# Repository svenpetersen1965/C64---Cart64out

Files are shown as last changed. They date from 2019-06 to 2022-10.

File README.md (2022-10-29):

# C64---Cart64out
Cart64out is a breakout board for the Commodore C64 Expansion Port 

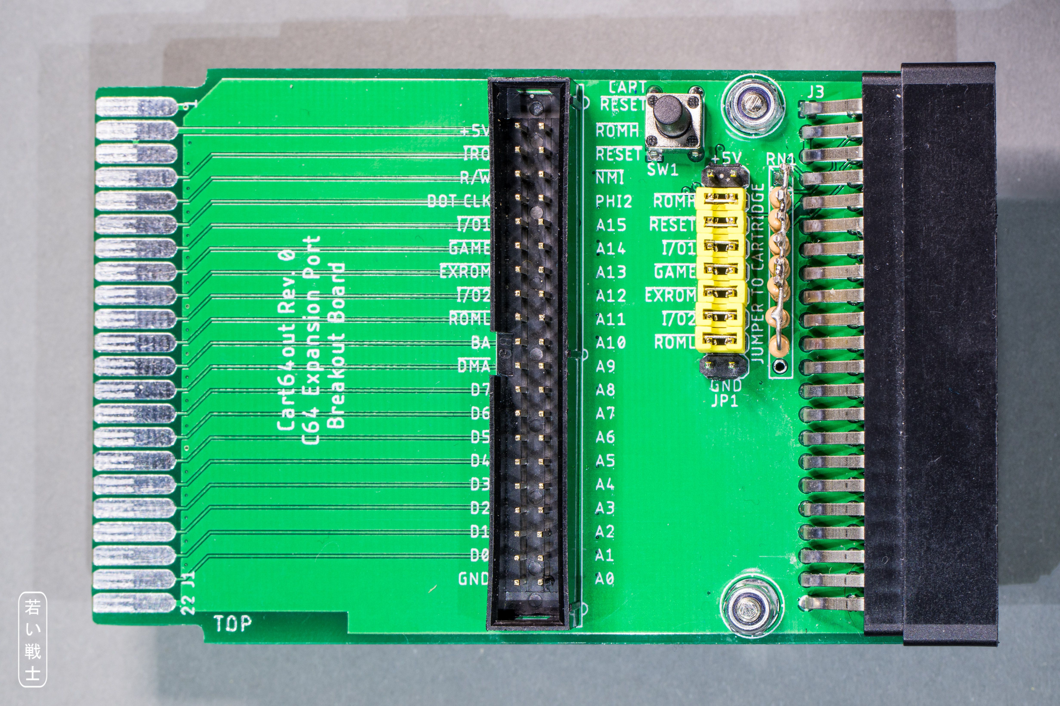
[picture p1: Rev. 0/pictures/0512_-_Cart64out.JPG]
Cart64out


All signals of the C64 expansion port are connected to a box pin header. This way, they can be displayed 
with a logic analyzer or an oscilloscope. A helpful feature for analysing the functionality for a cartridge.
Some configuration and chip select signals are connected to a jumper, hence they can be interrupted by pulling 
a jumper, which might be useful for copying a cartridge. To provide a perfect timing for this, a micro controller 
could be connected to the Jumper JP1.

Also the signals from J2 can be connected to a bread board. The two GND and two +5V pins on JP1 are intended for this purpose.

# Rev. 0a
This revision is a derivative of Rev. 0. It offers two additional mounting holes, in case this board is used to be an extension of the port (not tested, yet).

# Rev. 1
Rev. one has four mounting holes and additional signals (/IRQ , /NMI and /DMA) on the pin header JP1. 
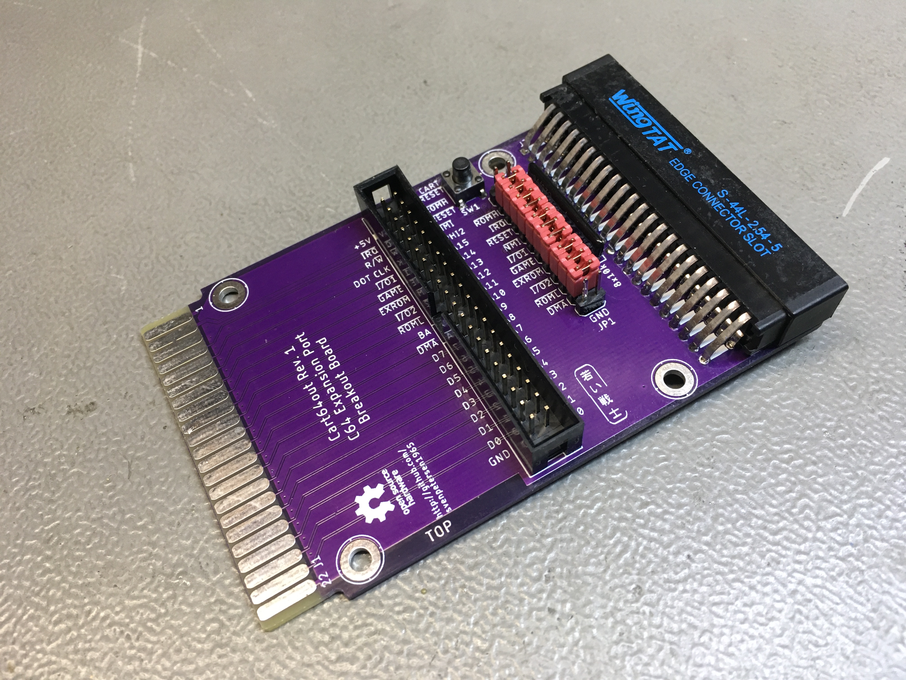
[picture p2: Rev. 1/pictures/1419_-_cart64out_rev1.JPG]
Cart64out


# Calculation of the BOM
The compnent prices (PBC included) were summed up. The total costs are 2.99€ (depending on the part sourcing). No shipping fees are included.

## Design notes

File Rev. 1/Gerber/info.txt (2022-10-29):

      
       Board: Cart64out
       Rev.:  1
  
       Files:
       ======
  
       All Gerber files are generated in extended gerber format (RS274X)
       *.TOP        : Film top copper
       *.BOT        :  -"- bottom copper
       *.STC        :  -"- top soldermask 
       *.STS        :  -"- bottom soldermask
       *.PLC        :  -"- silk screen top
       *.DK         : Drills plated Through (Excellon)
       *.NDK        : Drills not plated Through (Excellon)
       *.OUT        : Board outline

       Board Size:
       ===========
       Length     :   97.0 mm
       Width      :   62.0 mm
       Thickness  :   1.6 mm
       Material   :   FR 4
       Copper     :   35 um
       Surface    :   HASL
       
       Remarks:
       ========

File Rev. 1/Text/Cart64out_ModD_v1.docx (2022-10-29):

C64 Cart64out Rev. 1

Module description

# Introduction

This board is a breakout board for the C64 (C128) expansion port. It can also serve several other purposes:

- Expansion port breakout board for connecting a scope or logic analyzer
- Breakout board for connecting a bread board
- Cartridge read out and analysis tool
- A simple reset-switch

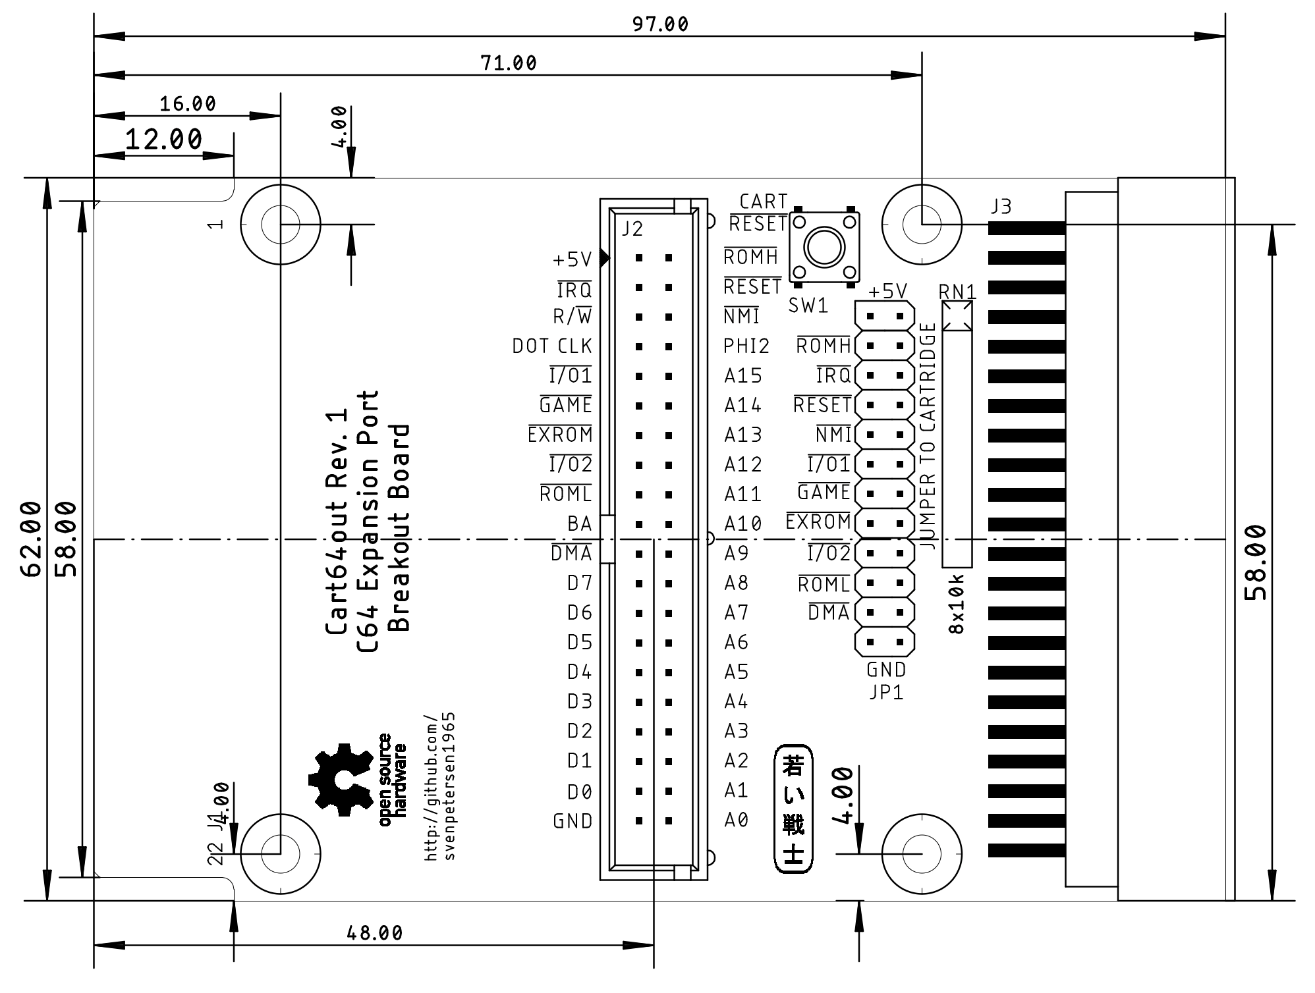
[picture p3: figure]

Figure 1: Cart64out dimensions

All signals of the expansion port are connected to the pin header J2. GND and +5V are only connected once to be able to use a standard 2x20p. pin header. All signals are connected to the edge connector J3. Some of those signals have to pass the jumper JP1, though, so they can be interrupted by pulling out the associated jumper. The resistor network RN1 serves as pull-up resistor on the cartridge side, so an open jumper means, that this signal is HIGH on the cartridge side.

The reset-switch SW1 is connected to the cartridge side of the reset signal. As long as the jumper labeled is closed, it is effective for the cartridge and the C64. While this jumper is open, it only resets the cartridge.

JP1 can also be controlled by a micro controller for a comfortable read out of the cartridge. The supply voltage +5V and GND are connected on adjacent pins for this purpose. Those jumper pins are not required to be closed with a jumper.

Signal | Pin | Pin | Signal
+5V | 1 | 2 | +5V
| 3 | 4
| 5 | 6
| 7 | 8
| 9 | 10
| 11 | 12
| 13 | 14
| 15 | 16
| 17 | 18
| 19 | 20
| 21 | 22
GND | 23 | 24 | GND

Table 1: Pinout of Jumper JP1

Cart64out aims at the experienced hardware amateur, who wants to get deeper into the functionality of C64 cartridges. It can also be helpful while repairing a C64, because some of the signals, like , PHI2 or DOT CLOCK or stuck address or data lines can be monitored by scope without opening the C64.

The drills serve to install bolts adjusted to height to support the Cart64out. A length of 17mm – 18mm works best for both sorts of cases (C64 and C64C).

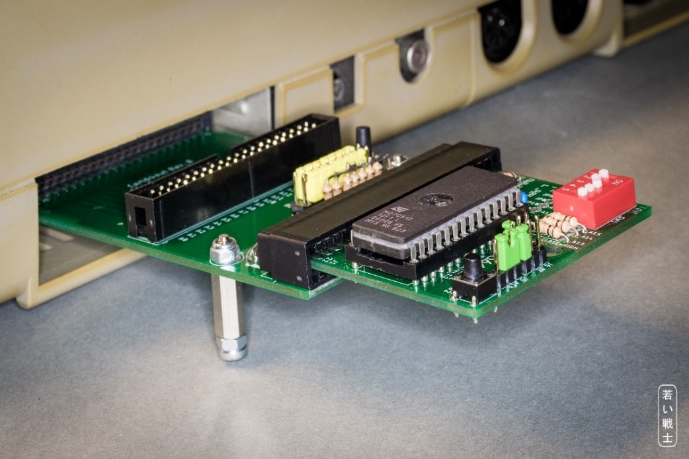
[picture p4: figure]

Figure 2: Supporting bolts

# Pinouts

## J1 – Expansion Port

Pin (TOP) | Signal | Pin | Signal (BOT)
1 | GND | A | GND
2 | +5V | B
3 | +5V | C
4 | | D
5 | R / | E | PHI2
6 | DOT CLOCK | F | A15
7 | | H | A14
8 | | J | A13
9 | | K | A12
10 | | L | A11
11 | | M | A10
12 | BA | N | A9
13 | | P | A8
14 | D7 | R | A7
15 | D6 | S | A6
16 | D5 | T | A5
17 | D4 | U | A4
18 | D3 | V | A3
19 | D2 | W | A2
20 | D1 | X | A1
21 | D0 | Y | A0
22 | GND | Z | GND

## J2 – Break out connector

2x20 box header, 2.54mm pitch

Pin | Signal | Pin | Signal
1 | +5V | 2
3 | | 4
5 | R / | 6
7 | DOT CLOCK | 8 | PHI2
9 | | 10 | A15
11 | | 12 | A14
13 | | 14 | A13
15 | | 16 | A12
17 | | 18 | A11
19 | BA | 20 | A10
21 | | 22 | A9
23 | D7 | 24 | A8
25 | D6 | 26 | A7
27 | D5 | 28 | A6
29 | D4 | 30 | A5
31 | D3 | 32 | A4
33 | D2 | 34 | A3
35 | D1 | 36 | A2
37 | D0 | 38 | A1
39 | GND | 40 | A0

## J3 – Cartridge Connector

Card Edge Connector 22x2P 2.54mm (0.1“) Right Angle

Pin (TOP) | Signal | Pin | Signal (BOT)
1 | GND | A | GND
2 | +5V | B
3 | +5V | C
4 | | D
5 | R / | E | PHI2
6 | DOT CLOCK | F | A15
7 | | H | A14
8 | | J | A13
9 | | K | A12
10 | | L | A11
11 | | M | A10
12 | BA | N | A9
13 | | P | A8
14 | D7 | R | A7
15 | D6 | S | A6
16 | D5 | T | A5
17 | D4 | U | A4
18 | D3 | V | A3
19 | D2 | W | A2
20 | D1 | X | A1
21 | D0 | Y | A0
22 | GND | Z | GND

The signals marked with * can be interrupted by a jumper (see Table 1).

# Revision History

## Rev. 0 → Rev. 0a

- Two mounting holes added

## Rev. 0a → Rev. 1

- Added , and to the pin header JP1 and made it suitable for solder bridges.

Cart64out_ModD_v1.docx 09.03.2022 16:22 Drafted by Sven Petersen Page 2 of 2 Doc.-No.: 122-6-01-01

Cart64out_ModD_v1.docx 09.03.2022 16:22 Drafted by Sven Petersen Page 1 of 1 Doc.-No.: 122-6-01-01

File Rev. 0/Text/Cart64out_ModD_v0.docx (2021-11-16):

C64 Cart64out Rev. 0

Module description

# Introduction

This board is a breakout board for the C64 (C128) expansion port. It can also serve several other purposes:

- Expansion port breakout board for connecting a scope or logic analyzer
- Breakout board for connecting a bread board
- Cartridge read out and analysis tool
- A simple reset-switch

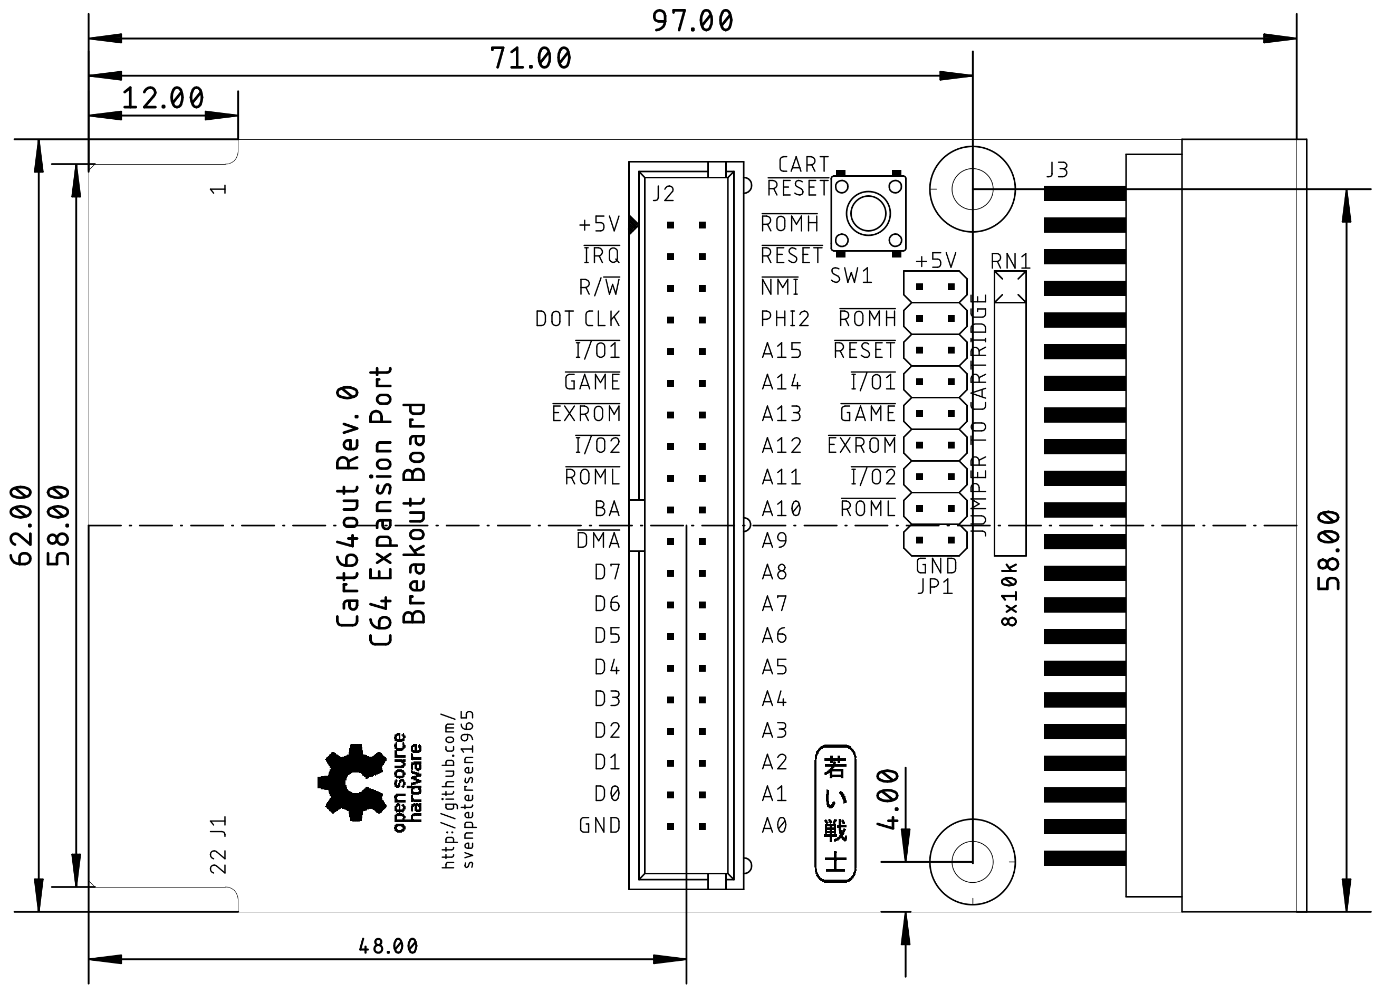
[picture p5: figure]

Figure 1: Cart64out dimensions

All signals of the expansion port are connected to the pin header J2. GND and +5V are only connected once to be able to use a standard 2x20p. pin header. All signals are connected to the edge connector J3. Some of those signals have to pass the jumper JP1, though, so they can be interrupted by pulling out the associated jumper. The resistor network RN1 serves as pull-up resistor on the cartridge side, so an open jumper means, that this signal is HIGH on the cartridge side.

The reset-switch SW1 is connected to the cartridge side of the reset signal. As long as the jumper labeled is closed, it is effective for the cartridge and the C64. While this jumper is open, it only resets the cartridge.

JP1 can also be controlled by a micro controller for a comfortable read out of the cartridge. The supply voltage +5V and GND are connected on adjacent pins for this purpose. Those jumper pins are not required to be closed with a jumper.

Signal | Pin | Pin | Signal
+5V | 1 | 2 | +5V
| 3 | 4
| 5 | 6
| 7 | 8
| 9 | 10
| 11 | 12
| 13 | 14
| 15 | 16
GND | 17 | 18 | GND

Table 1: Pinout of Jumper JP1

Cart64out aims at the experienced hardware amateur, who wants to get deeper into the functionality of C64 cartridges. It can also be helpful while repairing a C64, because some of the signals, like , PHI2 or DOT CLOCK or stuck address or data lines can be monitored by scope without opening the C64.

The drills serve to install bolts adjusted to height to support the Cart64out. A length of 17mm – 18mm works best for both sorts of cases (C64 and C64C).

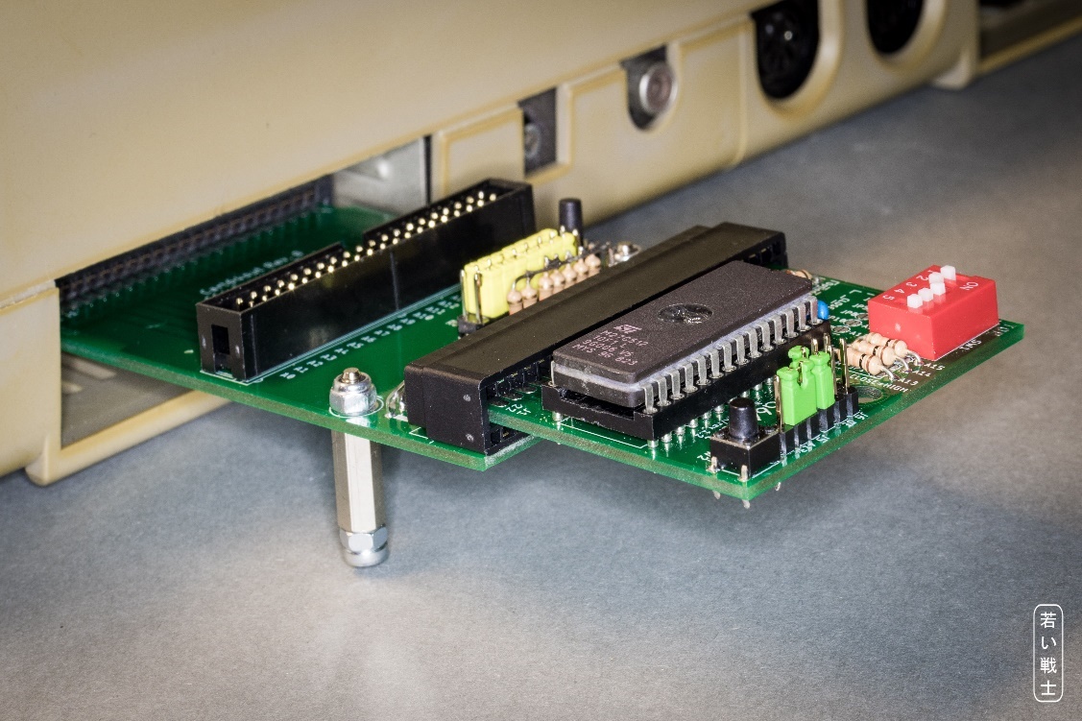
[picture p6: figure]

Figure 2: Supporting bolts

# Pinouts

## J1 – Expansion Port

Pin (TOP) | Signal | Pin | Signal (BOT)
1 | GND | A | GND
2 | +5V | B
3 | +5V | C
4 | | D
5 | R / | E | PHI2
6 | DOT CLOCK | F | A15
7 | | H | A14
8 | | J | A13
9 | | K | A12
10 | | L | A11
11 | | M | A10
12 | BA | N | A9
13 | | P | A8
14 | D7 | R | A7
15 | D6 | S | A6
16 | D5 | T | A5
17 | D4 | U | A4
18 | D3 | V | A3
19 | D2 | W | A2
20 | D1 | X | A1
21 | D0 | Y | A0
22 | GND | Z | GND

## J2 – Break out connector

2x20 box header, 2.54mm pitch

Pin | Signal | Pin | Signal
1 | +5V | 2
3 | | 4
5 | R / | 6
7 | DOT CLOCK | 8 | PHI2
9 | | 10 | A15
11 | | 12 | A14
13 | | 14 | A13
15 | | 16 | A12
17 | | 18 | A11
19 | BA | 20 | A10
21 | | 22 | A9
23 | D7 | 24 | A8
25 | D6 | 26 | A7
27 | D5 | 28 | A6
29 | D4 | 30 | A5
31 | D3 | 32 | A4
33 | D2 | 34 | A3
35 | D1 | 36 | A2
37 | D0 | 38 | A1
39 | GND | 40 | A0

## J3 – Cartridge Connector

Card Edge Connector 22x2P 2.54mm (0.1“) Right Angle

Pin (TOP) | Signal | Pin | Signal (BOT)
1 | GND | A | GND
2 | +5V | B
3 | +5V | C
4 | | D
5 | R / | E | PHI2
6 | DOT CLOCK | F | A15
7 | | H | A14
8 | | J | A13
9 | | K | A12
10 | | L | A11
11 | | M | A10
12 | BA | N | A9
13 | | P | A8
14 | D7 | R | A7
15 | D6 | S | A6
16 | D5 | T | A5
17 | D4 | U | A4
18 | D3 | V | A3
19 | D2 | W | A2
20 | D1 | X | A1
21 | D0 | Y | A0
22 | GND | Z | GND

The signals marked with * can be interrupted by a jumper (see Table 1).

Cart64out_ModD_v0.docx 16.11.2021 14:32 Drafted by Sven Petersen Page 2 of 2 Doc.-No.: 122-6-01-00

Cart64out_ModD_v0.docx 16.11.2021 14:32 Drafted by Sven Petersen Page 1 of 1 Doc.-No.: 122-6-01-00

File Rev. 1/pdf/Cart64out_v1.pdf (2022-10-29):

# Project Documentation

## C64 Cart64out

## Project number: 122

## Revision: 1

## Date: 27.02.2022

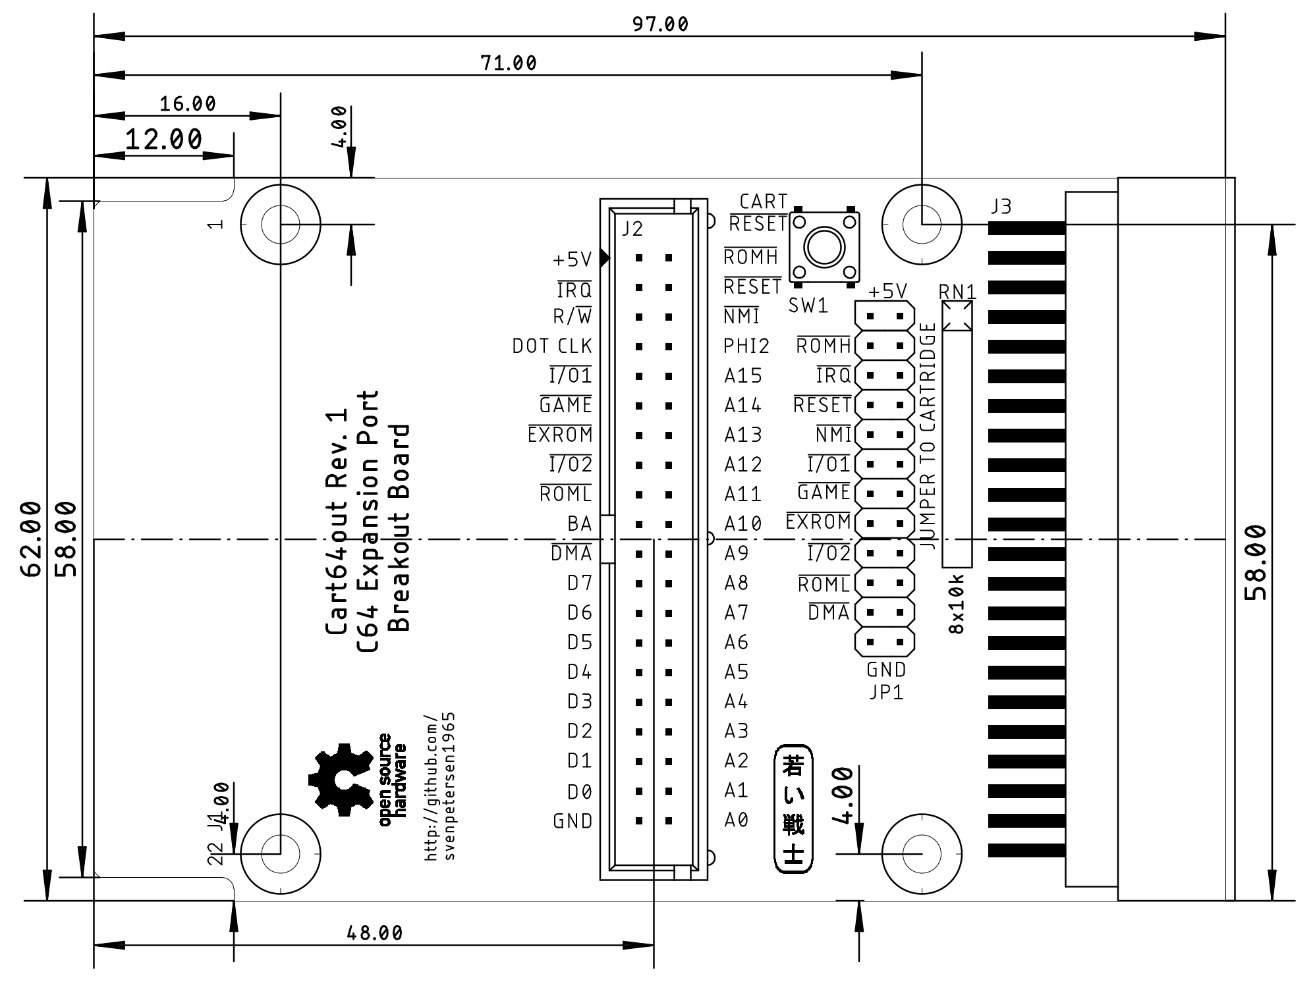
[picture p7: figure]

Cart64out_ModD_v1.docx | | 09.03.2022 16:22
Drafted by Sven Petersen | Page 1 of 5 | Doc.-No.: 122-6-01-01

### C64 Cart64out Rev. 1

### Module description

## Introduction

This board is a breakout board for the C64 (C128) expansion port. It can also serve several other purposes:

- Expansion port breakout board for connecting a scope or logic analyzer
- Breakout board for connecting a bread board
- Cartridge read out and analysis tool
- A simple reset-switch

Figure 1: Cart64out dimensions

All signals of the expansion port are connected to the pin header J2. GND and +5V are only connected once to be able to use a standard 2x20p. pin header. All signals are connected to the edge connector J3. Some of those signals have to pass the jumper JP1, though, so they can be interrupted by pulling out the associated jumper. The resistor network RN1 serves as pull-up resistor on the cartridge side, so an open jumper means, that this signal is HIGH on the cartridge side.

The reset-switch SW1 is connected to the cartridge side of the reset signal. As long as the jumper labeled RESET is closed, it is effective for the cartridge and the C64. While this jumper is open, it only resets the cartridge.

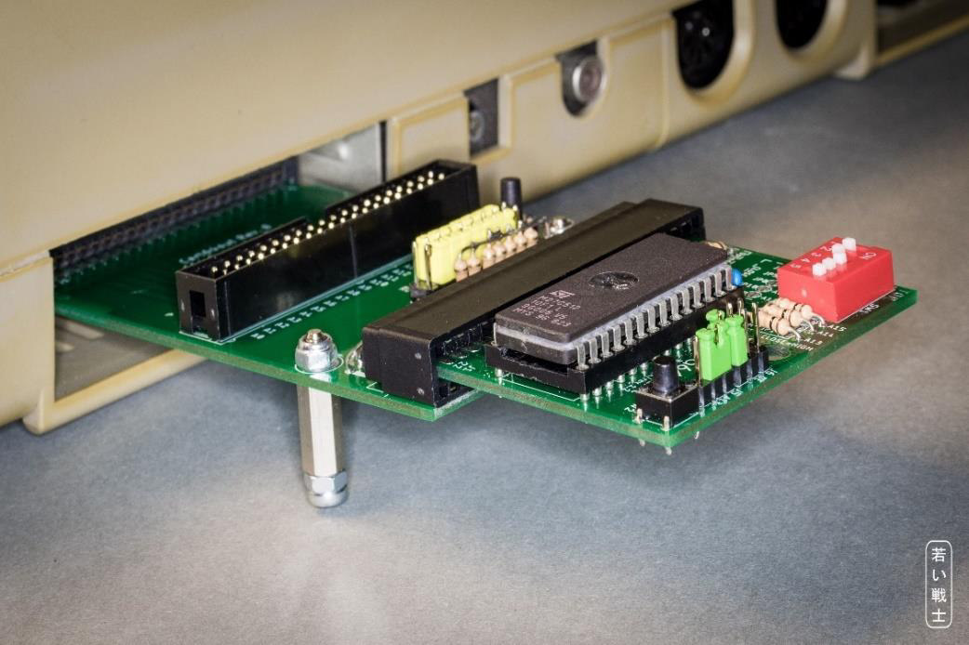
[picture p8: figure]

Cart64out_ModD_v1.docx | | 09.03.2022 16:22
Drafted by Sven Petersen | Page 2 of 5 | Doc.-No.: 122-6-01-01

JP1 can also be controlled by a micro controller for a comfortable read out of the cartridge. The supply voltage +5V and GND are connected on adjacent pins for this purpose. Those jumper pins are not required to be closed with a jumper.

Signal Pin | Pin Signal
+5V | 1 | 2 | +5V
ROMH | 3 | 4 | ROMH*
IRQ | 5 | 6 | IRQ*
RESET | 7 | 8 | RESET*
NMI | 9 | 10 | NMI*
I/O1 | 11 | 12 | I/O1*
GAME | 13 | 14 | GAME*
EXROM | 15 | 16 | EXROM*
I/O2 | 17 | 18 | I/O2*
ROML | 19 | 20 | ROML*
DMA | 21 | 22 | DMA*
GND | 23 | 24 | GND
Table 1: Pinout of Jumper JP1

Cart64out aims at the experienced hardware amateur, who wants to get deeper into the functionality of C64 cartridges. It can also be helpful while repairing a C64, because some of the signals, like RESET , PHI2 or DOT CLOCK or stuck address or data lines can be monitored by scope without opening the C64.

The drills serve to install bolts adjusted to height to support the Cart64out. A length of 17mm – 18mm works best for both sorts of cases (C64 and C64C).

Figure 2: Supporting bolts

Cart64out_ModD_v1.docx | | 09.03.2022 16:22
Drafted by Sven Petersen | Page 3 of 5 | Doc.-No.: 122-6-01-01

## Pinouts

### J1 – Expansion Port

Pin (TOP) Signal | Pin Signal (BOT)
1 | GND | A | GND
2 | +5V | B | ROMH
3 | +5V | C | RESET
4 IRQ | | D NMI
5 R / W | | E PHI2
6 | DOT CLOCK | F | A15
7 I/O1 | | H A14
8 GAME | | J A13
9 EXROM | | K A12
10 I/O2 | | L A11
11 | ROML | M | A10
12 | BA | N | A9
13 DMA | | P A8
14 | D7 | R | A7
15 | D6 | S | A6
16 | D5 | T | A5
17 | D4 | U | A4
18 | D3 | V | A3
19 | D2 | W | A2
20 | D1 | X | A1
21 | D0 | Y | A0
22 | GND | Z | GND

### J2 – Break out connector

2x20 box header, 2.54mm pitch

Pin Signal | Pin Signal
1 | +5V | 2 | ROMH
3 IRQ | | 4 RESET
5 R / W | | 6 NMI
7 | DOT CLOCK | 8 | PHI2
9 I/O1 | | 10 A15
11 GAME | | 12 A14
13 EXROM | | 14 A13
15 I/O2 | | 16 A12
17 ROML | | 18 A11

Cart64out_ModD_v1.docx | | 09.03.2022 16:22
Drafted by Sven Petersen | Page 4 of 5 | Doc.-No.: 122-6-01-01
Pin Signal | Pin Signal
19 | BA | 20 | A10
21 DMA | | 22 A9
23 | D7 | 24 | A8
25 | D6 | 26 | A7
27 | D5 | 28 | A6
29 | D4 | 30 | A5
31 | D3 | 32 | A4
33 | D2 | 34 | A3
35 | D1 | 36 | A2
37 | D0 | 38 | A1
39 | GND | 40 | A0

### J3 – Cartridge Connector

Card Edge Connector 22x2P 2.54mm (0.1“) Right Angle

Pin (TOP) Signal | Pin Signal (BOT)
1 | GND | A | GND
2 | +5V | B | ROMH*
3 | +5V | C | RESET*
4 IRQ* | | D NMI*
5 R / W | | E PHI2
6 | DOT CLOCK | F | A15
7 I/O1* | | H A14
8 GAME* | | J A13
9 EXROM* | | K A12
10 I/O2* | | L A11
11 | ROML* | M | A10
12 | BA | N | A9
13 DMA* | | P A8
14 | D7 | R | A7
15 | D6 | S | A6
16 | D5 | T | A5
17 | D4 | U | A4
18 | D3 | V | A3
19 | D2 | W | A2
20 | D1 | X | A1
21 | D0 | Y | A0
22 | GND | Z | GND
The signals marked with * can be interrupted by a jumper (see Table 1).

Cart64out_ModD_v1.docx | | 09.03.2022 16:22
Drafted by Sven Petersen | Page 5 of 5 | Doc.-No.: 122-6-01-01

## Revision History

### Rev. 0 → Rev. 0a

- Two mounting holes added

### Rev. 0a → Rev. 1

- Added IRQ , NMI and DMA to the pin header JP1 and made it suitable for solder

bridges.

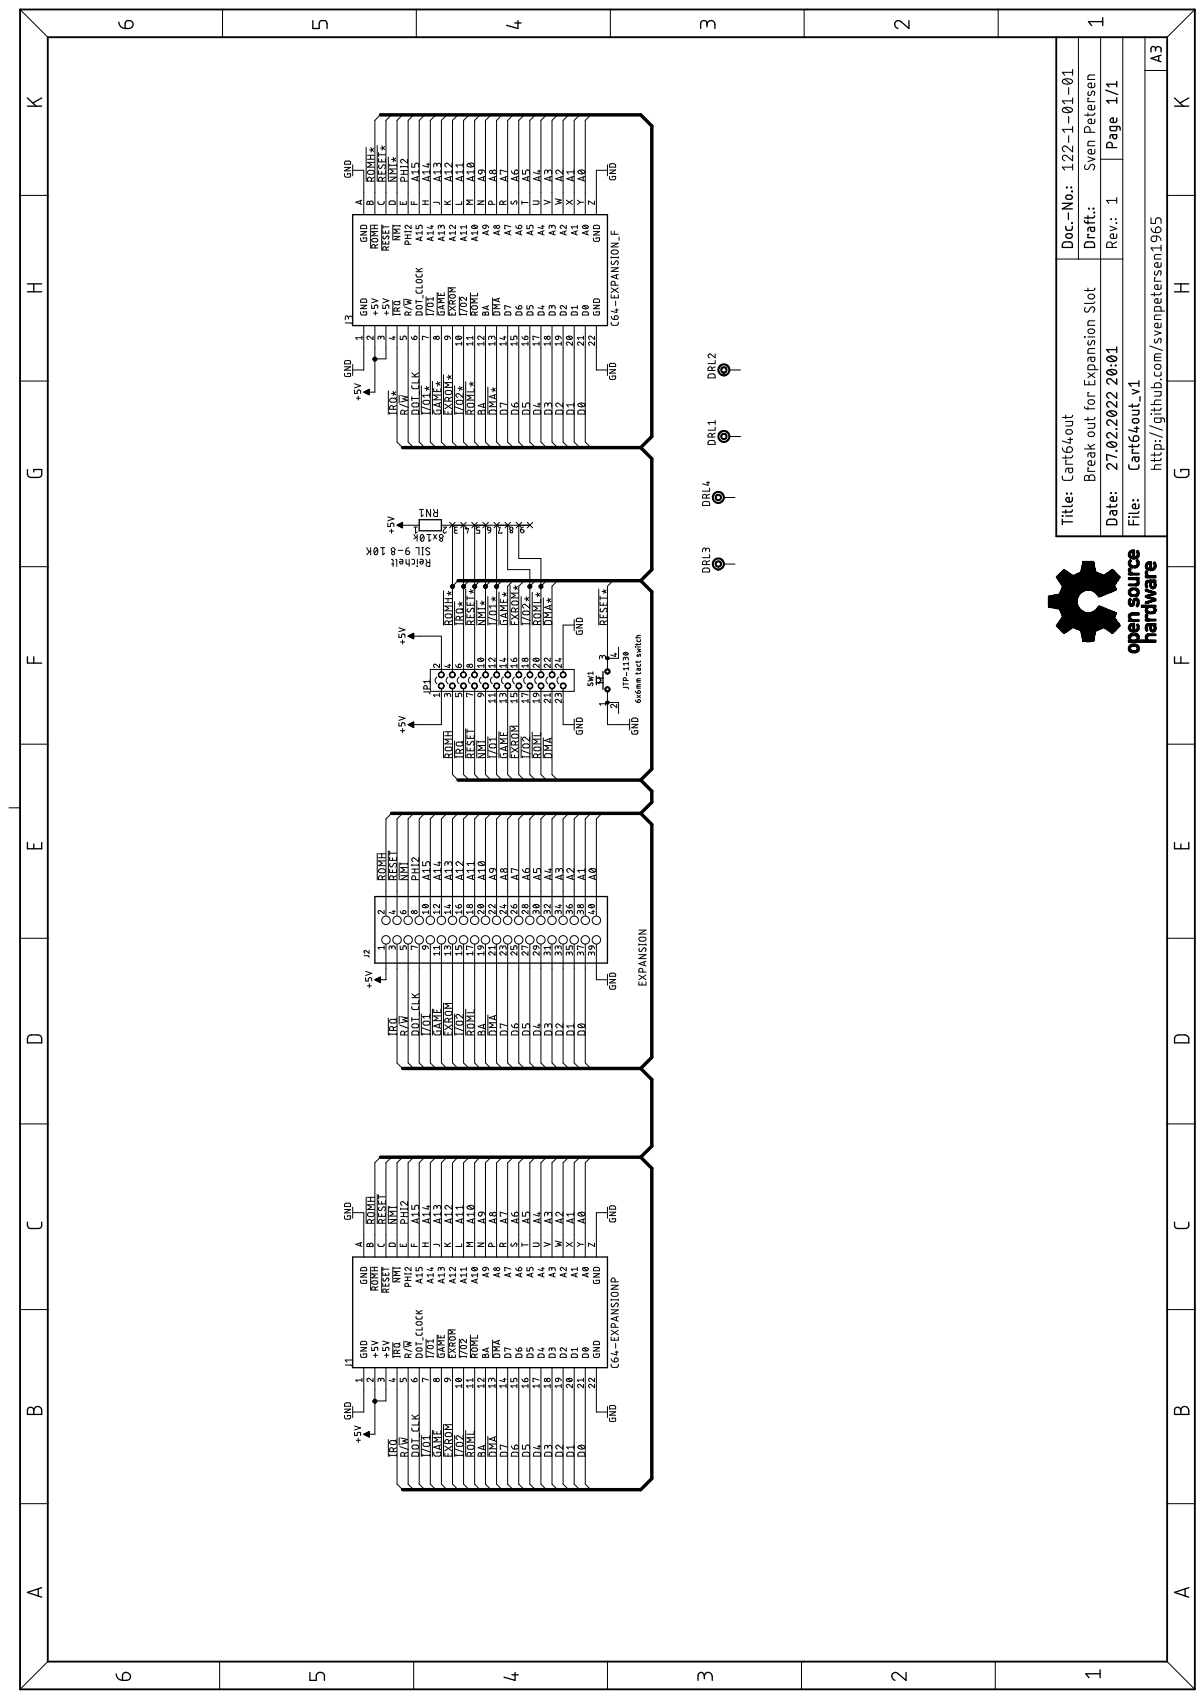
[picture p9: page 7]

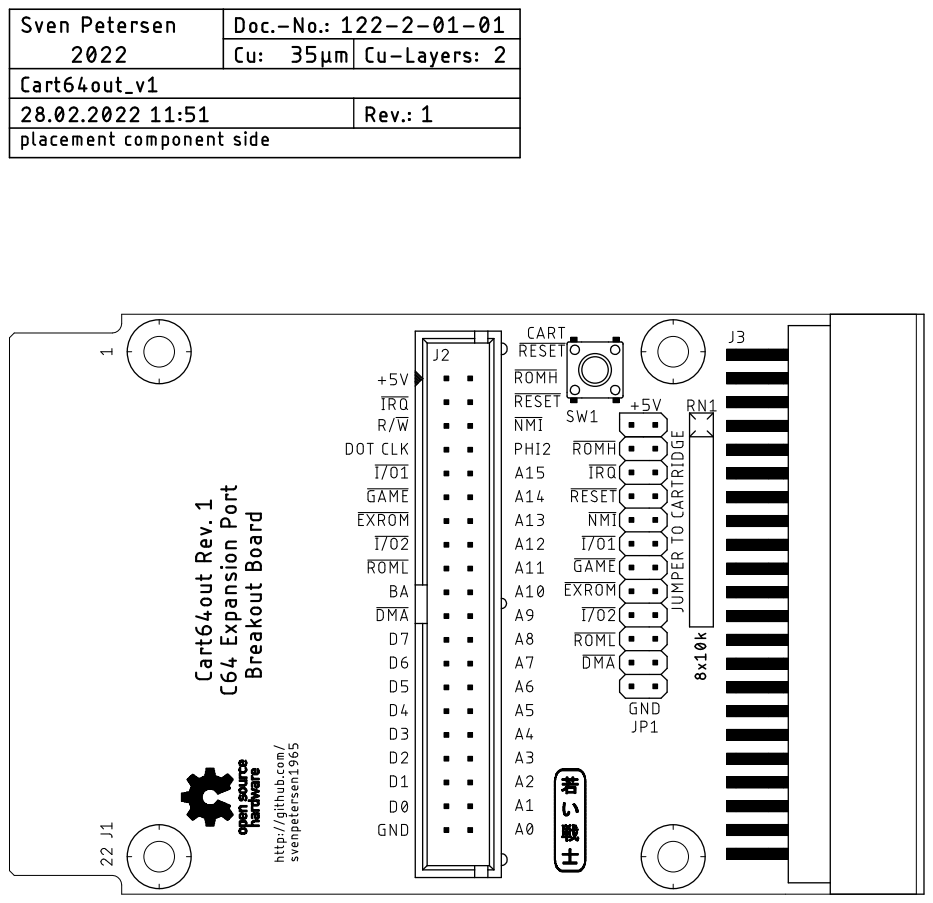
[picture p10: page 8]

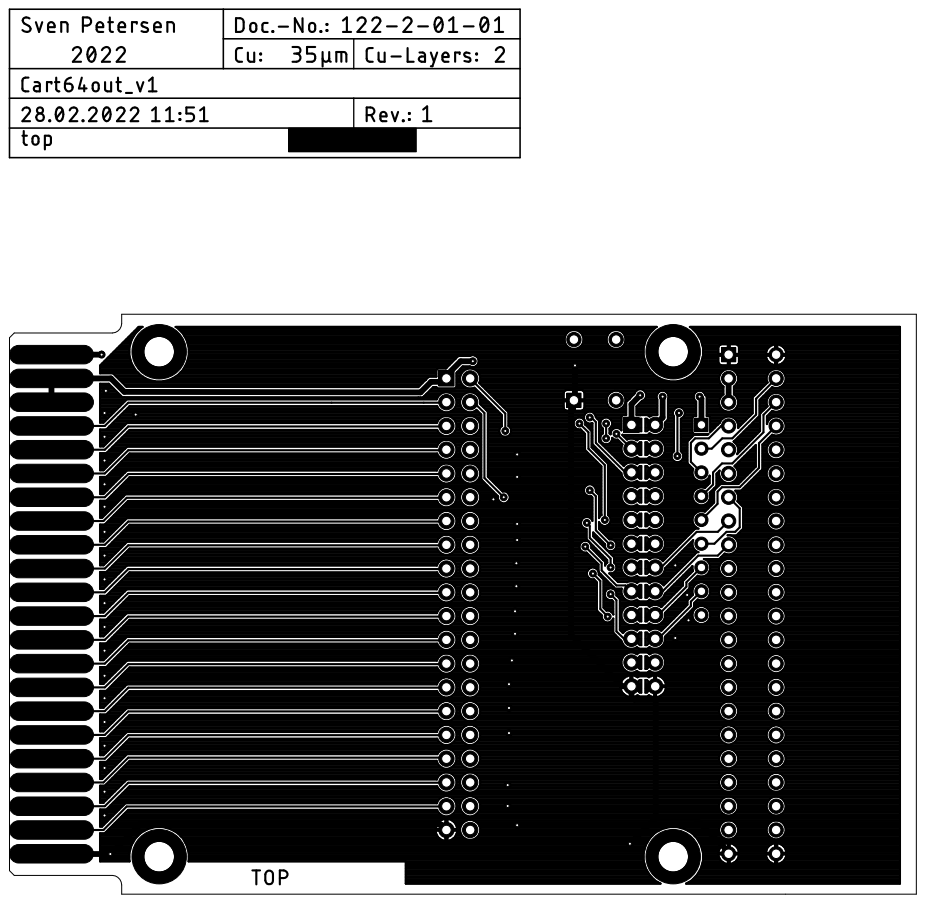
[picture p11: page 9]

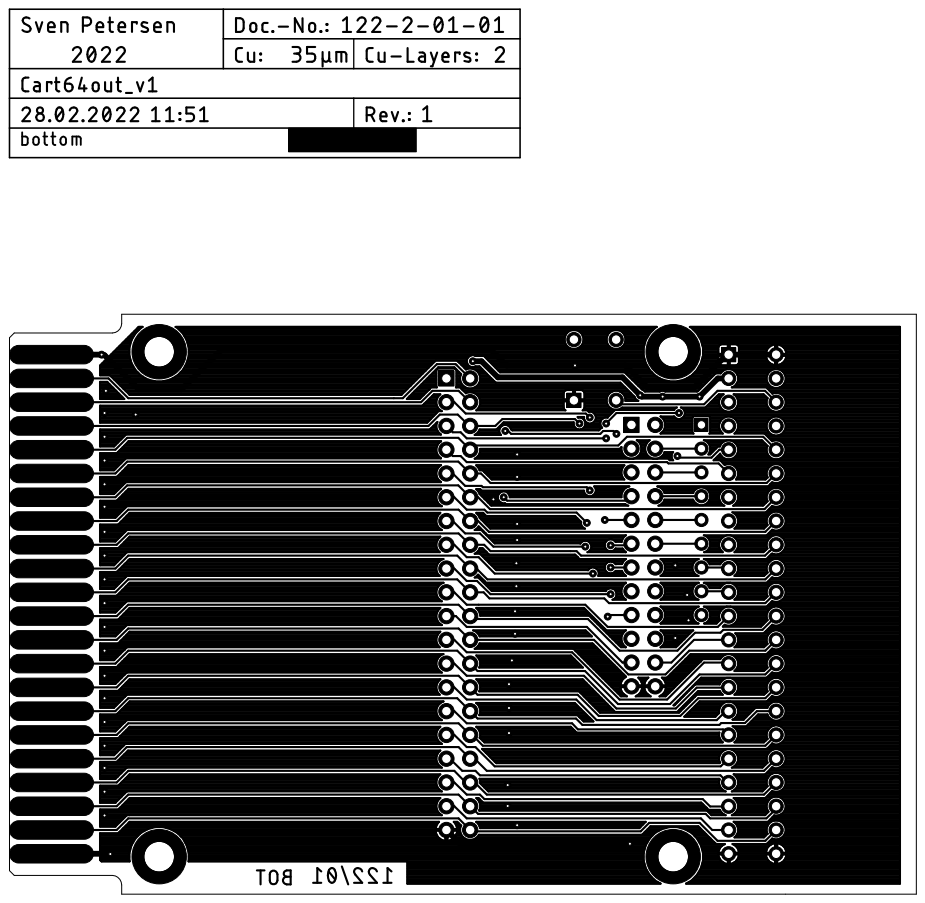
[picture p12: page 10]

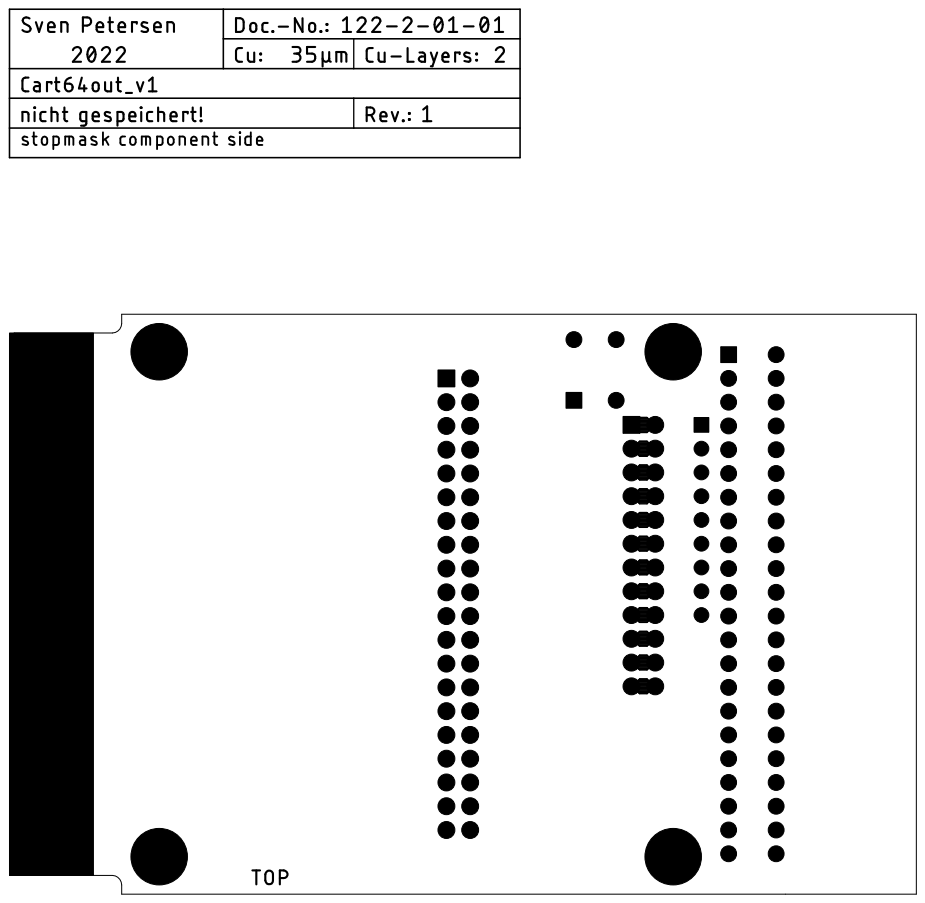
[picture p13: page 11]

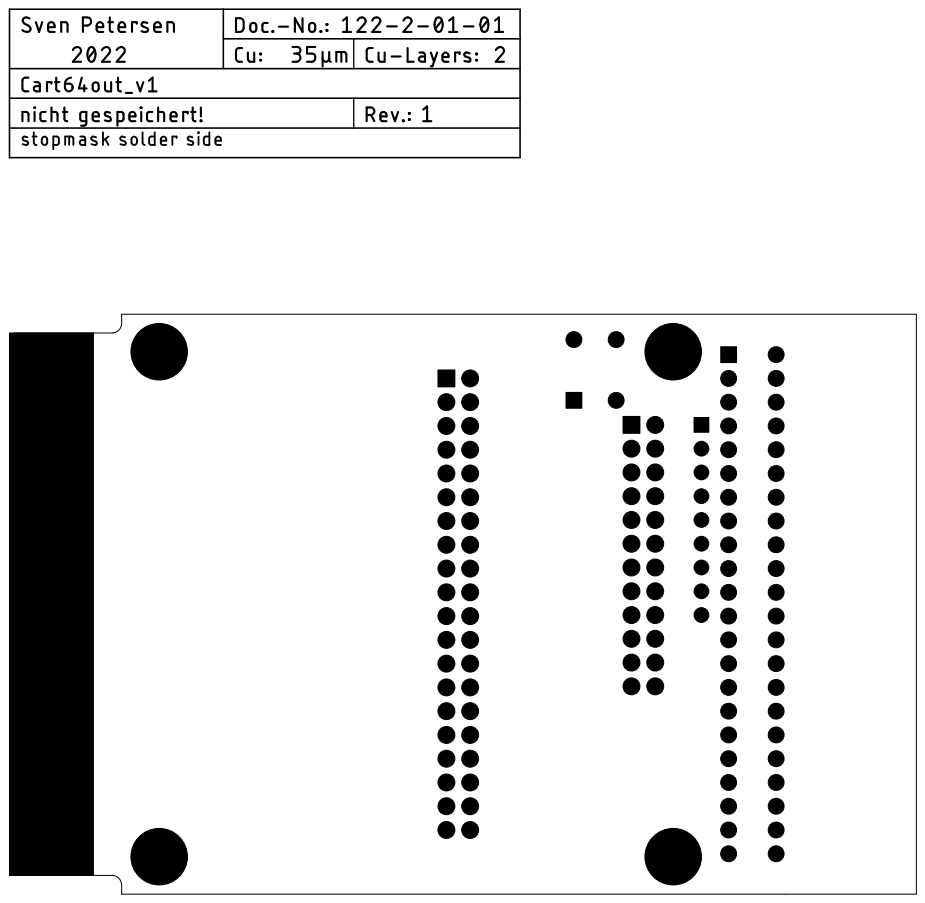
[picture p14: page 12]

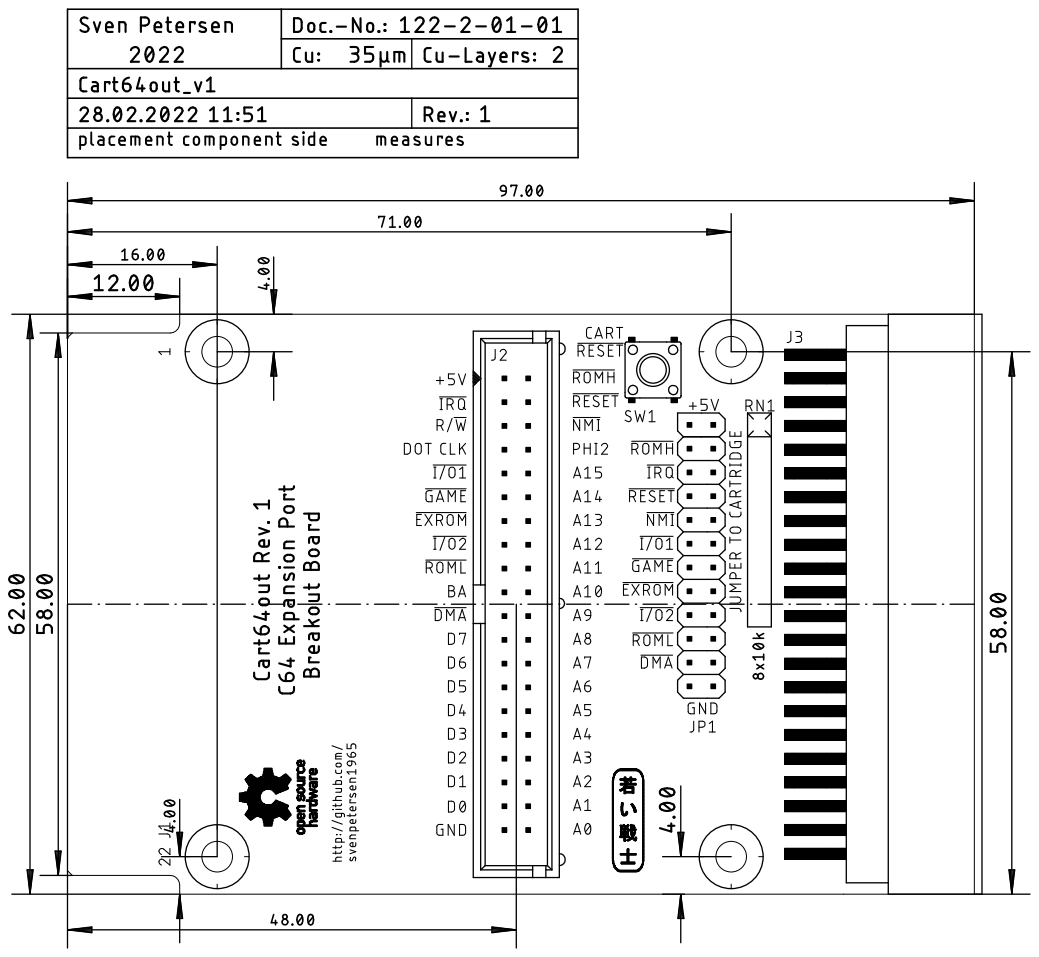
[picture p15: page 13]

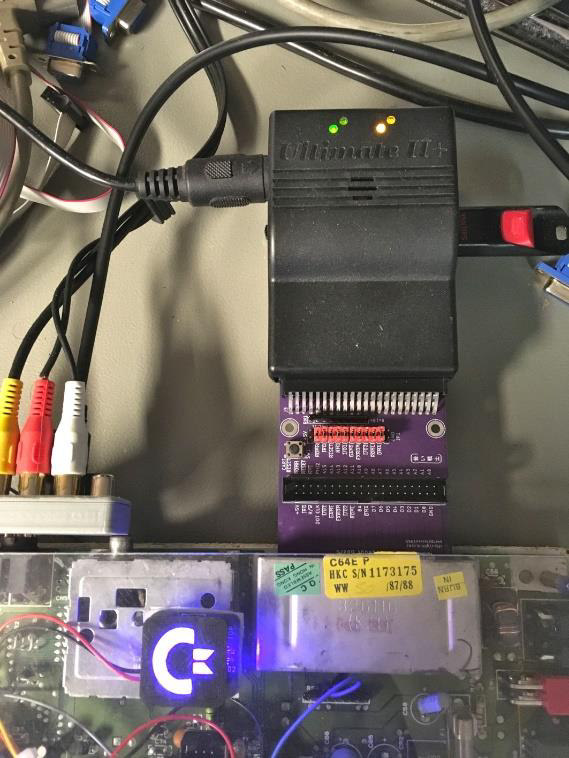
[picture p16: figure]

Cart64out_Test_v1.docx | | 30.10.2022 00:03
Drafted by Sven Petersen | Page 1 of 1 | Doc.-No.: 122-6-02-01

### C64 Cart64Out Rev. 1

### Testing

The tests were conducted with three different motherboards (250469 Rev. 4 and Rev B.) and several cartridges:

- Versa64Cart Rev. 1.6 with different software
- Final Cartridge III+
- Kernal64cart Rev. 1
- Dela DOS
- Handic FORTH 64
- Ultimate II+

All jumpers installed. All cartridges work flawlessly with the Cart64Out connected

Figure 1: Test with Ultimate II+

The reset-switch resets the system.

While inserted into the C64, J2 can be accessed and the labeling on both sides of the connector can be read.

Cart64Out is fully functional.

Pos. Qty Value Footprint Ref.-No. Comment

1 1 122-2-01-01 2 Layer PCB Rev. 1 2 layer, Cu 35µ, HASL, 97.0mmmx 62.0mm, 1.6mm FR4

2 1 2x20 boxed header 2X20WV J2 2x20, boxed pin header or standard pin header, e.g.

reichelt.de WSL 40G

3 1 2x12 2X12(2.54) JP1 standard pin header 2x12 pins, 2.54mm (=0.1") pitch

4 10 Jumper 2.54mm pitch jumper (JP1) Standard jumper (0,1"), e.g. reichelt.de MPE 149-2-002-F1
5 1 8x10k RN-9 RN1 resistor network, 8 resistors 10k, SIL 9pin. E.G. reichelt.de

SIL 9-8 10K

6 1 2x22 pin edge connector,

90°

EXPANSION_OU

T

J3 1/5 x 5pc Industrial Card Edge Slot Socket Connector

22x2P 44P 2.54mm 0.1" Right Angle (https://www.ebay.de/itm/5pc-Industrial-Card-Edge-Slot-Socket-Connector-22x2P-44P-2-54mm-0-1-Right-Angle/130970275089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)

7 1 JTP-1130 JTP-1130 SW1 Standard 6x6mm tact switch, e.g. Namae JTP-1130 or any

other, e.g. reichelt.de JTP-1130

## C64 Cart64out Rev. 1

## Bill of Material Rev. 1.0

Cart64Out_BOM_v1_0.xlsx

Drafted by Sven Petersen Page 1 of 1

09.03.2022 16:24
Doc.No.: 122-5-01-01.0

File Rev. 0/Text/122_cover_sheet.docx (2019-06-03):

Project Documentation

C64 Cart64out

Project number: 122

Revision: 0

Date: 27.04.2019

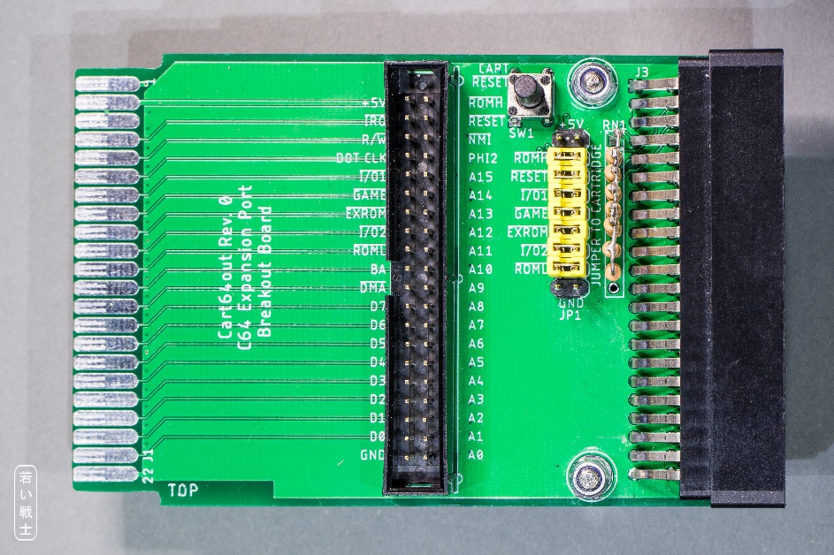
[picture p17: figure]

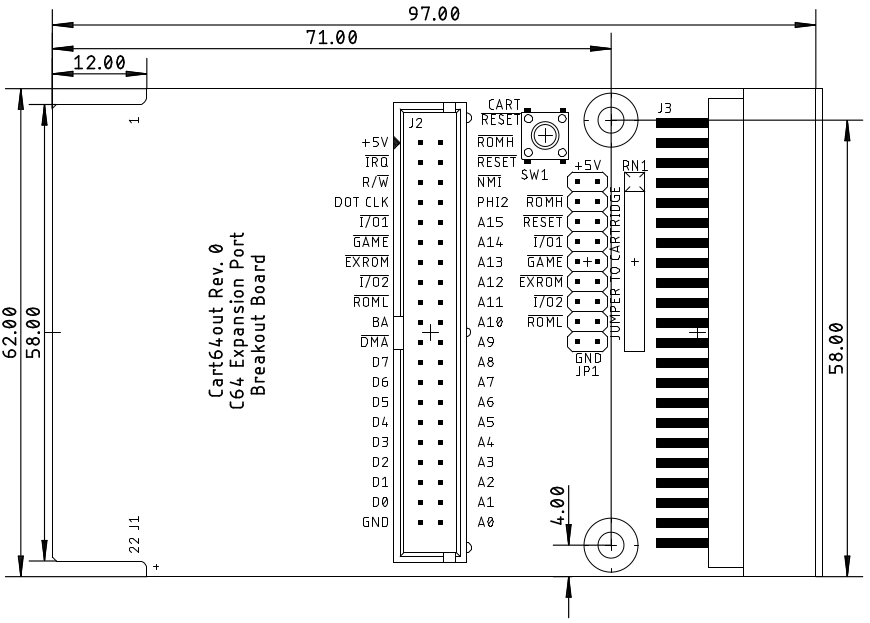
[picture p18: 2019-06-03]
Rev. 0/pictures/C64_Cart64out_mech.png

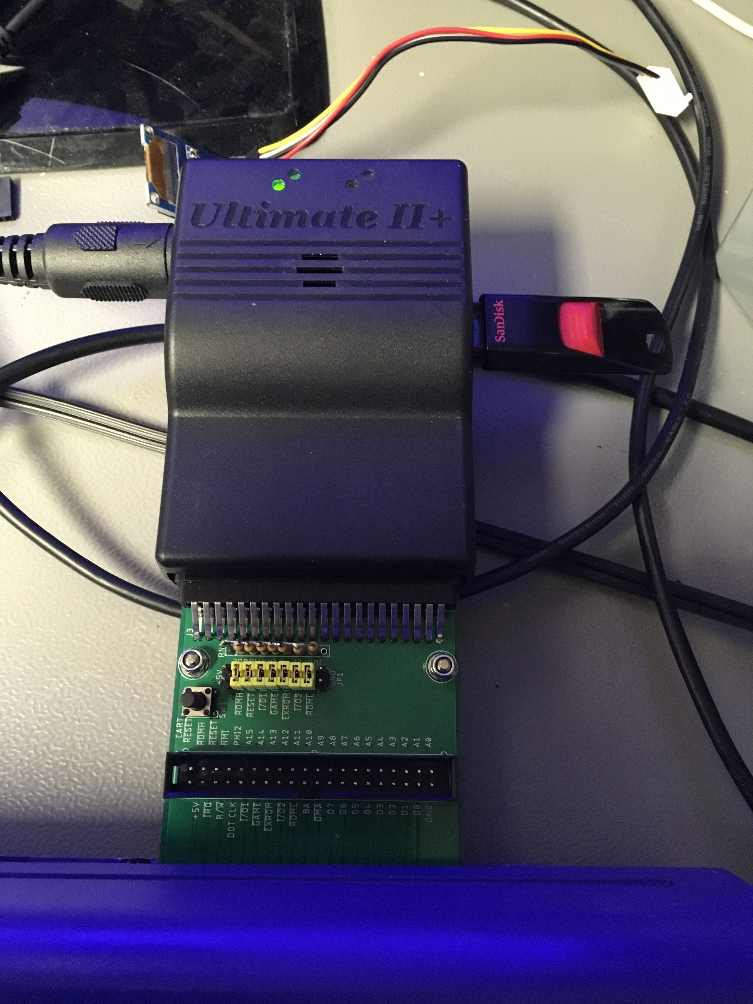
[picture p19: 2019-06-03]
Rev. 0/pictures/1924_-_Cart64out_Ultimate_II+.JPG

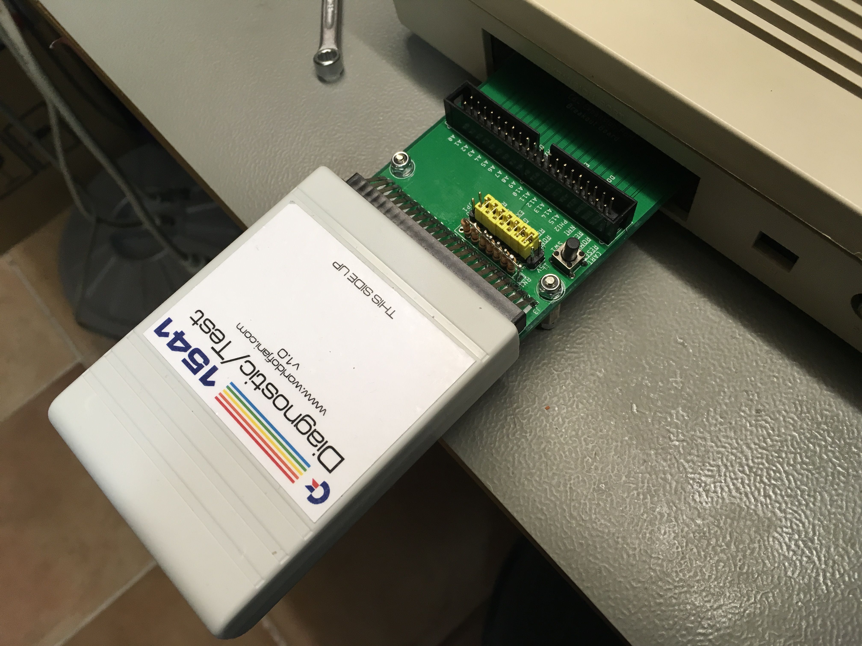
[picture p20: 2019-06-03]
Rev. 0/pictures/1918_-_Cart64out_1541_diagnostic.JPG

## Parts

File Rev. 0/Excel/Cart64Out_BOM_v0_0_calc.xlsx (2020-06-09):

C64 Cart64out Rev. 0
Bill of Material Rev. 0.0
Pos. | Qty | Value | €/ea | € | Comment
1 | 1 | 122-2-01-00 | 1.00 € | 1.00 € | 2 layer, Cu 35µ, HASL, 97.0mmmx 62.0mm, 1.6mm FR4
2 | 1 | 2x20 boxed header | 0.20 € | 0.20 € | 2x20, boxed pin header or standard pin header, e.g. reichelt.de WSL 40G
3 | 1 | 2x09 | 0.06 € | 0.06 € | pin header 2x9 pins, 2.54mm (=0.1") pitch, e.g. reichelt.de RND 205-00640
4 | 7 | Jumper 2.54mm pitch | 0.02 € | 0.14 € | Standard jumper (0,1"), e.g. reichelt.de MPE 149-2-002-F1
5 | 1 | 8x10k | 0.11 € | 0.11 € | resistor network, 8 resistors 10k, SIL 9pin. E.G. reichelt.de SIL 9-8 10K
6 | 1 | 2x22 pin edge connector, 90° | 1.33 € | 1.33 € | 1/5 x 5pc Industrial Card Edge Slot Socket Connector 22x2P 44P 2.54mm 0.1" Right Angle (https://www.ebay.de/itm/5pc-Industrial-Card-Edge-Slot-Socket-Connector-22x2P-44P-2-54mm-0-1-Right-Angle/130970275089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)
7 | 1 | JTP-1130 | 0.15 € | 0.15 € | Standard 6x6mm tact switch, e.g. Namae JTP-1130 or any other, e.g. reichelt.de JTP-1130
 |  |  | Total | 2.99 €

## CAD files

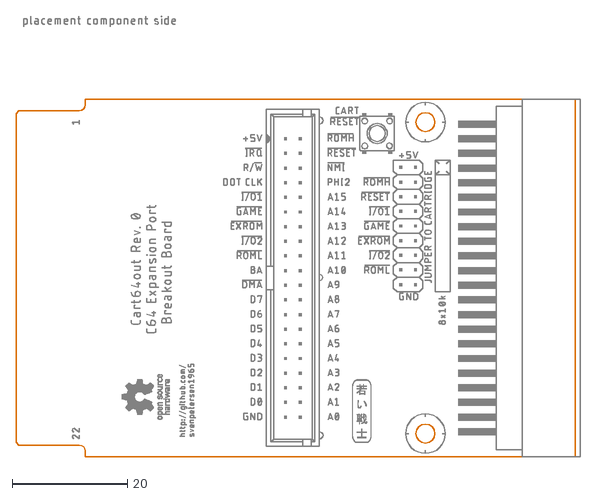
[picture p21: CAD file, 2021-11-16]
Rev. 0/dxf/Cart64out.dxf
97.8 x 76.4

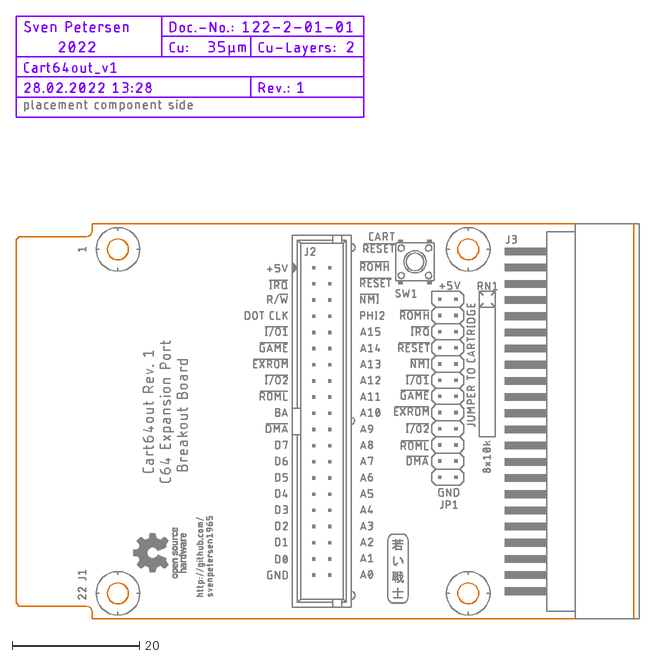
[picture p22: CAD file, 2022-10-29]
Rev. 1/dxf/Cart64out_v1.dxf
97.8 x 94.6

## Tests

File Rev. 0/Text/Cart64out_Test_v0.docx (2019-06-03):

C64 Cart64Out Rev. 0

Testing

The tests were conducted with three different motherboards (250407 and 250469 Rev. 4 and Rev B.) and several cartridges:

- Versa64Cart Rev. 1.1 and Rev. 1 with different software
- Final Cartridge III+
- Extern Kernal 8 (REX Datentechnik 9628)
- Dela DOS
- Handic FORTH 64
- Ultimate II+

All jumpers installed. All cartridges work flawlessly with the Cart64Out connected

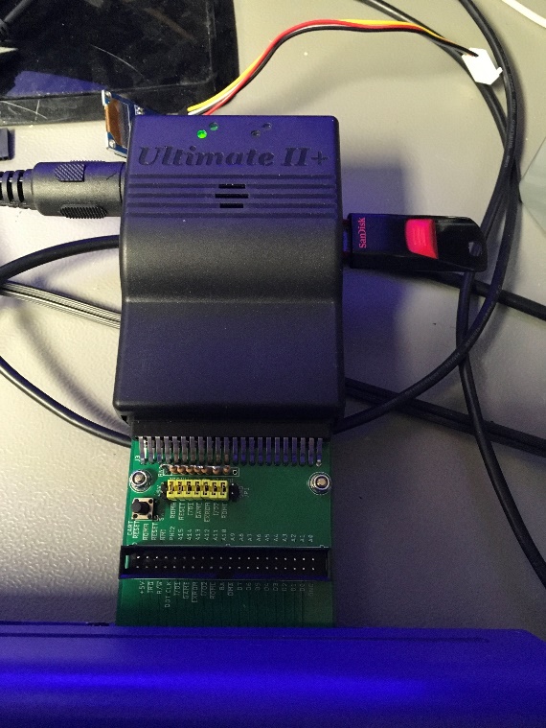
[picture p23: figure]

Figure 1: Test with Ultimate II+

The reset-switch resets the system.

While inserted into the C64, J2 can be accessed and the labeling on both sides of the connector can be read.

Cart64Out is fully functional.

Cart64out_Test_v0.docx 03.06.2019 16:44 Drafted by Sven Petersen Page 2 of 2 Doc.-No.: 000-6-00-00

Cart64out_Test_v0.docx 03.06.2019 16:44 Drafted by Sven Petersen Page 1 of 1 Doc.-No.: 122-6-02-00

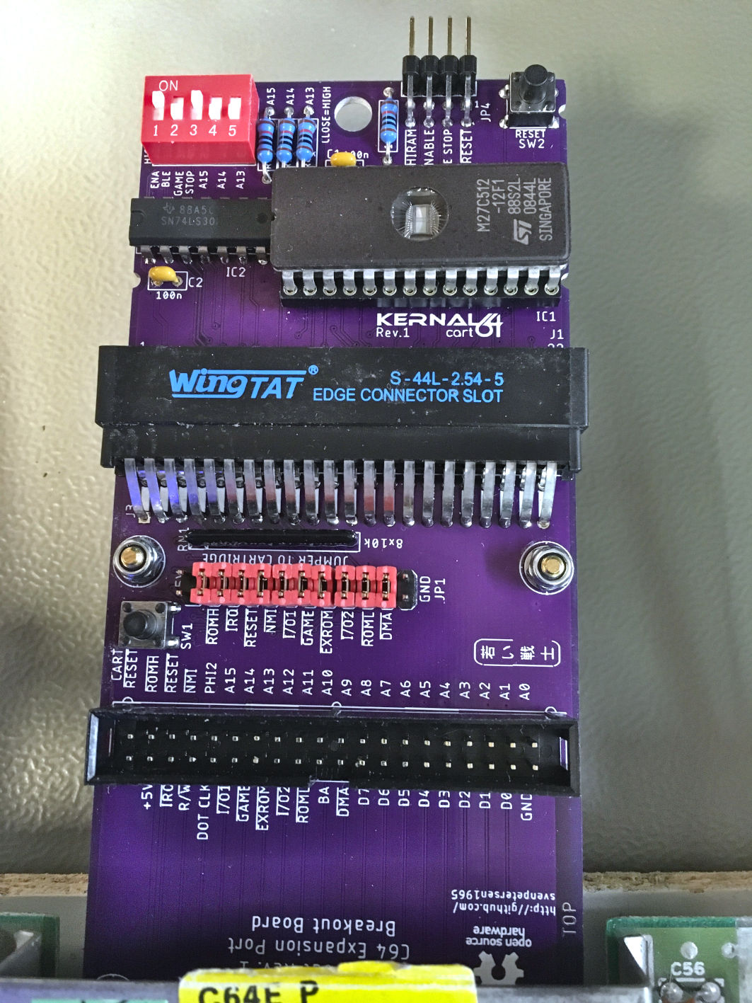
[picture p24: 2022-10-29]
Rev. 1/pictures/1424_-_Test_Kernal64cart.JPG

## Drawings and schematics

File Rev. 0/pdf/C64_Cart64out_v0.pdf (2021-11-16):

# Project Documentation

## C64 Cart64out

## Project number: 122

## Revision: 0

## Date: 27.04.2019

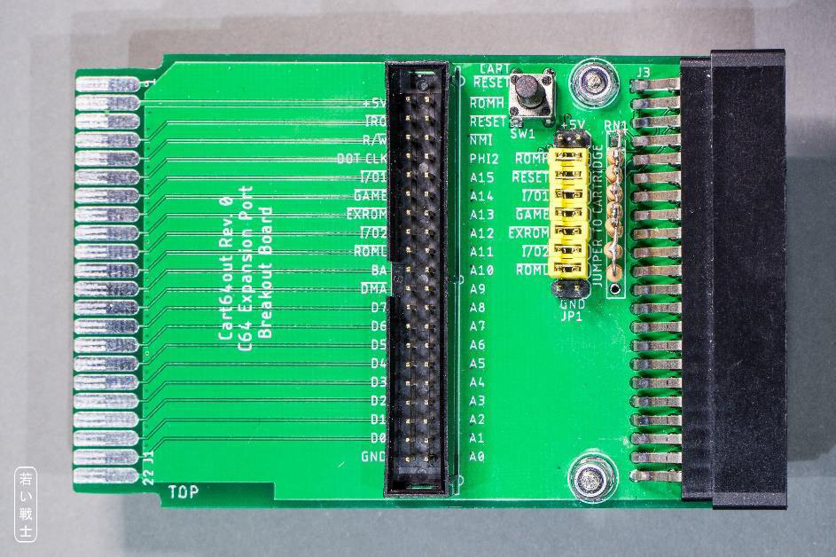
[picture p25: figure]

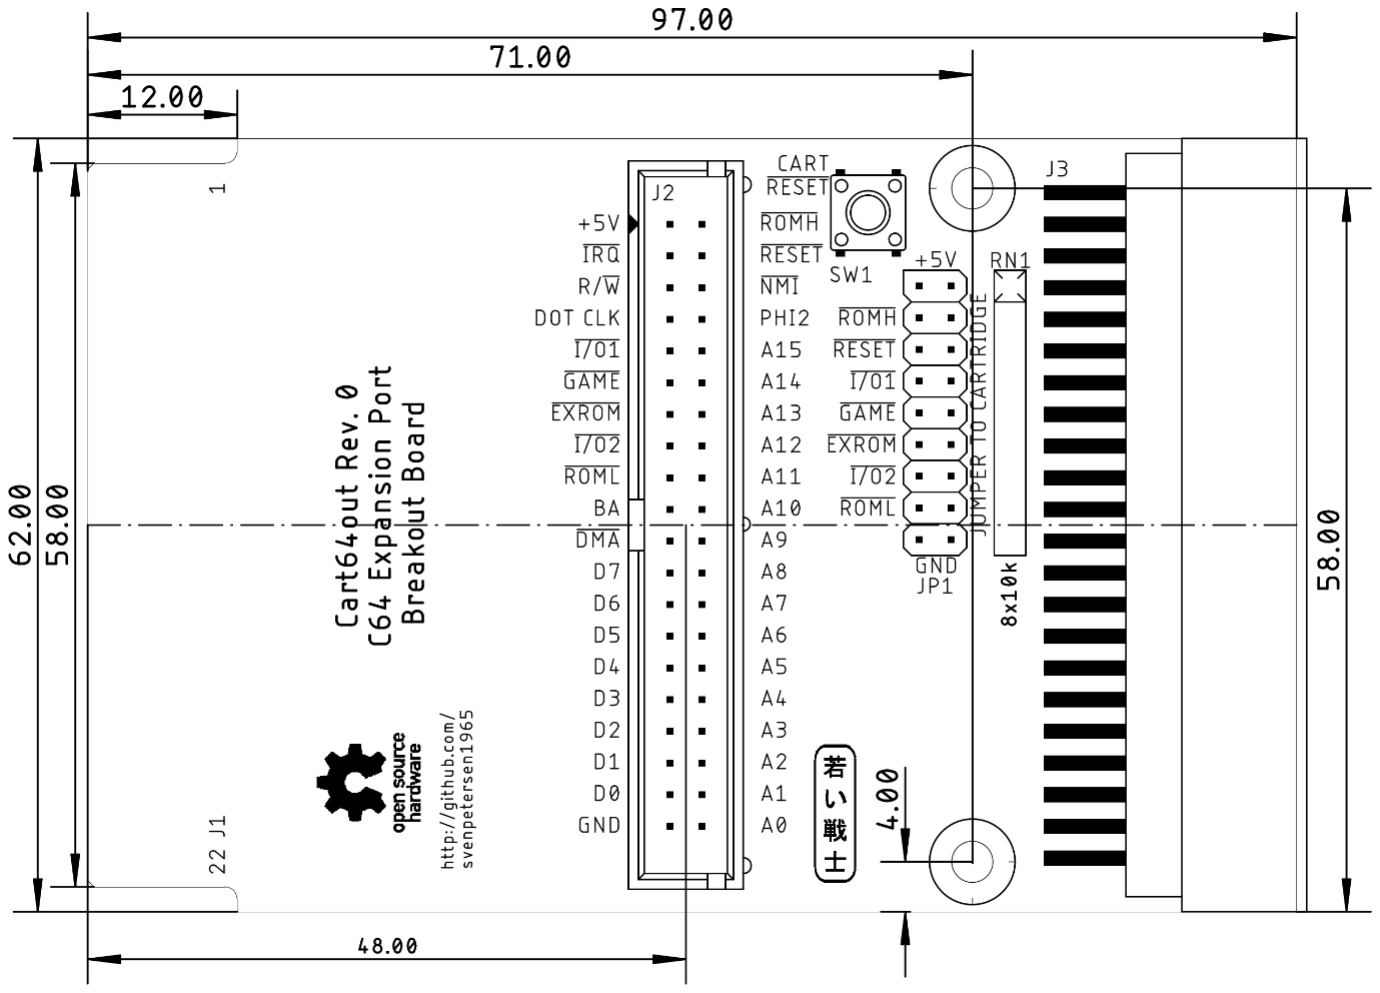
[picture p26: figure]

Cart64out_ModD_v0.docx | | 16.11.2021 14:32
Drafted by Sven Petersen | Page 1 of 4 | Doc.-No.: 122-6-01-00

### C64 Cart64out Rev. 0

### Module description

## Introduction

This board is a breakout board for the C64 (C128) expansion port. It can also serve several other purposes:

- Expansion port breakout board for connecting a scope or logic analyzer
- Breakout board for connecting a bread board
- Cartridge read out and analysis tool
- A simple reset-switch

Figure 1: Cart64out dimensions

All signals of the expansion port are connected to the pin header J2. GND and +5V are only connected once to be able to use a standard 2x20p. pin header. All signals are connected to the edge connector J3. Some of those signals have to pass the jumper JP1, though, so they can be interrupted by pulling out the associated jumper. The resistor network RN1 serves as pull-up resistor on the cartridge side, so an open jumper means, that this signal is HIGH on the cartridge side.

The reset-switch SW1 is connected to the cartridge side of the reset signal. As long as the jumper labeled RESET is closed, it is effective for the cartridge and the C64. While this jumper is open, it only resets the cartridge.

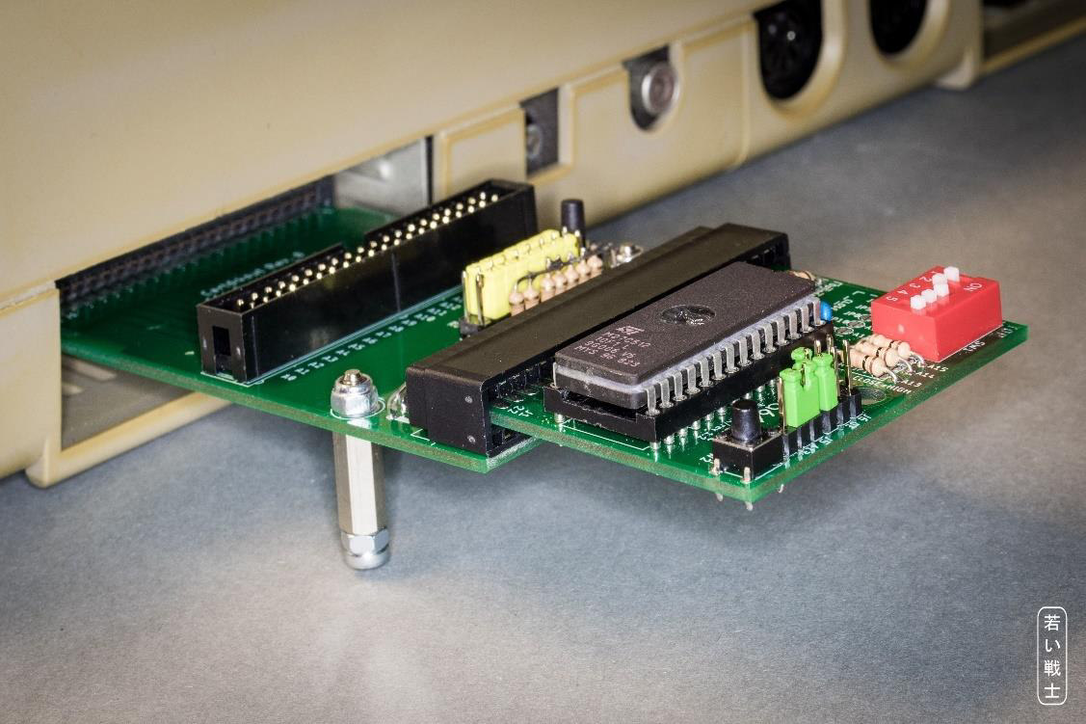
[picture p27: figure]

Cart64out_ModD_v0.docx | | 16.11.2021 14:32
Drafted by Sven Petersen | Page 2 of 4 | Doc.-No.: 122-6-01-00

JP1 can also be controlled by a micro controller for a comfortable read out of the cartridge. The supply voltage +5V and GND are connected on adjacent pins for this purpose. Those jumper pins are not required to be closed with a jumper.

Signal Pin | Pin Signal
+5V | 1 | 2 | +5V
ROMH | 3 | 4 | ROMH*
RESET | 5 | 6 | RESET*
I/O1 | 7 | 8 | I/O1*
GAME | 9 | 10 | GAME*
EXROM | 11 | 12 | EXROM*
I/O2 | 13 | 14 | I/O2*
ROML | 15 | 16 | ROML*
GND | 17 | 18 | GND
Table 1: Pinout of Jumper JP1

Cart64out aims at the experienced hardware amateur, who wants to get deeper into the functionality of C64 cartridges. It can also be helpful while repairing a C64, because some of the signals, like RESET , PHI2 or DOT CLOCK or stuck address or data lines can be monitored by scope without opening the C64.

The drills serve to install bolts adjusted to height to support the Cart64out. A length of 17mm – 18mm works best for both sorts of cases (C64 and C64C).

Figure 2: Supporting bolts

Cart64out_ModD_v0.docx | | 16.11.2021 14:32
Drafted by Sven Petersen | Page 3 of 4 | Doc.-No.: 122-6-01-00

## Pinouts

### J1 – Expansion Port

Pin (TOP) Signal | Pin Signal (BOT)
1 | GND | A | GND
2 | +5V | B | ROMH
3 | +5V | C | RESET
4 IRQ | | D NMI
5 R / W | | E PHI2
6 | DOT CLOCK | F | A15
7 I/O1 | | H A14
8 GAME | | J A13
9 EXROM | | K A12
10 I/O2 | | L A11
11 | ROML | M | A10
12 | BA | N | A9
13 DMA | | P A8
14 | D7 | R | A7
15 | D6 | S | A6
16 | D5 | T | A5
17 | D4 | U | A4
18 | D3 | V | A3
19 | D2 | W | A2
20 | D1 | X | A1
21 | D0 | Y | A0
22 | GND | Z | GND

### J2 – Break out connector

2x20 box header, 2.54mm pitch

Pin Signal | Pin Signal
1 | +5V | 2 | ROMH
3 IRQ | | 4 RESET
5 R / W | | 6 NMI
7 | DOT CLOCK | 8 | PHI2
9 I/O1 | | 10 A15
11 GAME | | 12 A14
13 EXROM | | 14 A13
15 I/O2 | | 16 A12
17 ROML | | 18 A11

Cart64out_ModD_v0.docx | | 16.11.2021 14:32
Drafted by Sven Petersen | Page 4 of 4 | Doc.-No.: 122-6-01-00
Pin Signal | Pin Signal
19 | BA | 20 | A10
21 DMA | | 22 A9
23 | D7 | 24 | A8
25 | D6 | 26 | A7
27 | D5 | 28 | A6
29 | D4 | 30 | A5
31 | D3 | 32 | A4
33 | D2 | 34 | A3
35 | D1 | 36 | A2
37 | D0 | 38 | A1
39 | GND | 40 | A0
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

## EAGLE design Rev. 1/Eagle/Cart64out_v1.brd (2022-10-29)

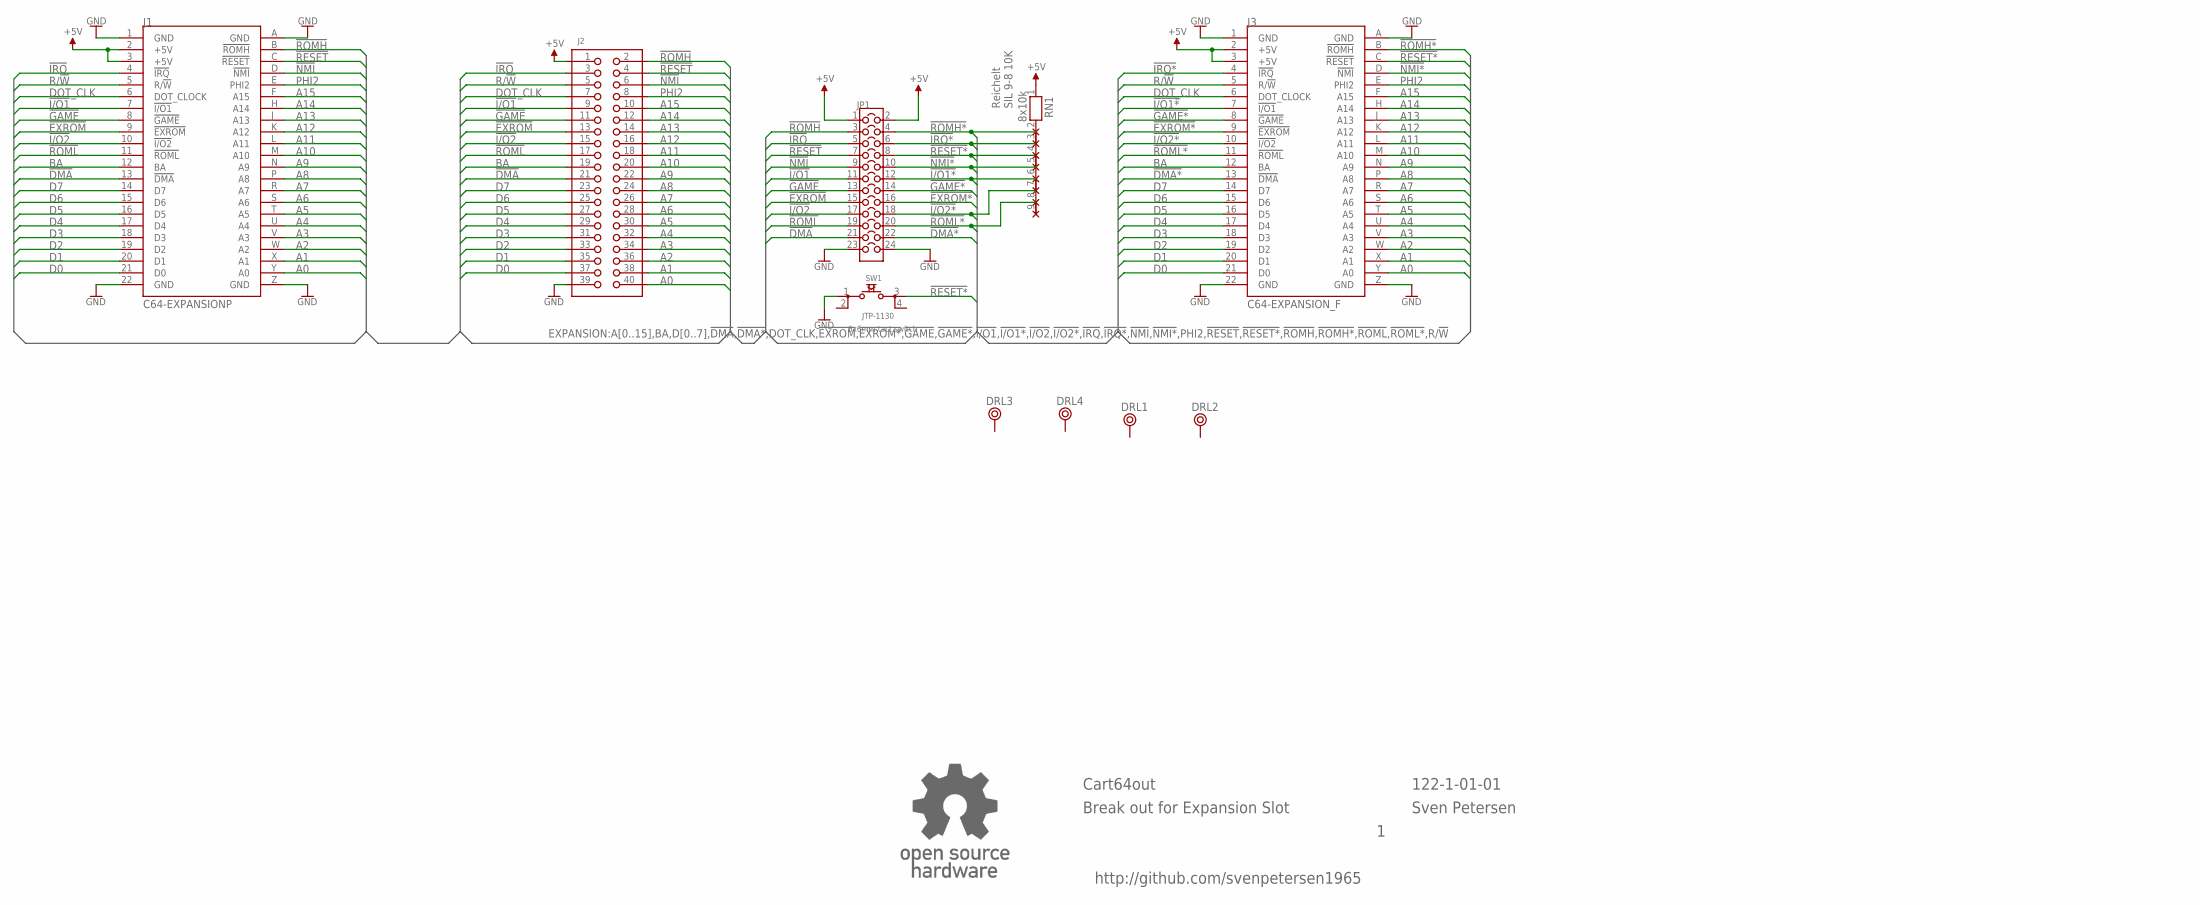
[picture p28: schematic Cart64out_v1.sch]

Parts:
DRL1, DRL2, DRL3, DRL4: BOHR3,3
J1: C64-EXPANSIONP; EXPPORT
J2: PINHD-2X20WV; 2X20WV
J3: C64-EXPANSION_F; EXPANSION_OUT
JP1: COMBI_2X12; COMBI-12X2
RN1: 8x10k; RN-9
SW1: JTP-1130
U$22: OPEN_SOURCE_HW; OPENHW

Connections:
!DMA: J1.13 (!DMA), J2.21, JP1.21
!DMA*: J3.13 (!DMA), JP1.22
!EXROM: J1.9 (!EXROM), J2.13, JP1.15
!EXROM*: J3.9 (!EXROM), JP1.16
!GAME: J1.8 (!GAME), J2.11, JP1.13
!GAME*: J3.8 (!GAME), JP1.14
!I/O1: J1.7 (!I/O1), J2.9, JP1.11
!I/O1*: J3.7 (!I/O1), JP1.12, RN1.6
!I/O2: J1.10 (!I/O2), J2.15, JP1.17
!I/O2*: J3.10 (!I/O2), JP1.18, RN1.7
!IRQ: J1.4 (!IRQ), J2.3, JP1.5
!IRQ*: J3.4 (!IRQ), JP1.6, RN1.3
!NMI: J1.D (!NMI), J2.6, JP1.9
!NMI*: J3.D (!NMI), JP1.10, RN1.5
!RESET: J1.C (!RESET), J2.4, JP1.7
!RESET*: J3.C (!RESET), JP1.8, RN1.4, SW1.3
!ROMH: J1.B (!ROMH), J2.2, JP1.3
!ROMH*: J3.B (!ROMH), JP1.4, RN1.2
!ROML: J1.11 (!ROML), J2.17, JP1.19
!ROML*: J3.11 (!ROML), JP1.20, RN1.8
+5V: J1.2 (+5V), J1.3 (+5V), J2.1, J3.2 (+5V), J3.3 (+5V), JP1.1, JP1.2, RN1.1
A0: J1.Y (A0), J2.40, J3.Y (A0)
A1: J1.X (A1), J2.38, J3.X (A1)
A2: J1.W (A2), J2.36, J3.W (A2)
A3: J1.V (A3), J2.34, J3.V (A3)
A4: J1.U (A4), J2.32, J3.U (A4)
A5: J1.T (A5), J2.30, J3.T (A5)
A6: J1.S (A6), J2.28, J3.S (A6)
A7: J1.R (A7), J2.26, J3.R (A7)
A8: J1.P (A8), J2.24, J3.P (A8)
A9: J1.N (A9), J2.22, J3.N (A9)
A10: J1.M (A10), J2.20, J3.M (A10)
A11: J1.L (A11), J2.18, J3.L (A11)
A12: J1.K (A12), J2.16, J3.K (A12)
A13: J1.J (A13), J2.14, J3.J (A13)
A14: J1.H (A14), J2.12, J3.H (A14)
A15: J1.F (A15), J2.10, J3.F (A15)
BA: J1.12 (BA), J2.19, J3.12 (BA)
D0: J1.21 (D0), J2.37, J3.21 (D0)
D1: J1.20 (D1), J2.35, J3.20 (D1)
D2: J1.19 (D2), J2.33, J3.19 (D2)
D3: J1.18 (D3), J2.31, J3.18 (D3)
D4: J1.17 (D4), J2.29, J3.17 (D4)
D5: J1.16 (D5), J2.27, J3.16 (D5)
D6: J1.15 (D6), J2.25, J3.15 (D6)
D7: J1.14 (D7), J2.23, J3.14 (D7)
DOT_CLK: J1.6 (DOT_CLOCK), J2.7, J3.6 (DOT_CLOCK)
GND: J1.1 (GND), J1.22 (GND), J1.A (GND), J1.Z (GND), J2.39, J3.1 (GND), J3.22 (GND), J3.A (GND), J3.Z (GND), JP1.23, JP1.24, SW1.1
PHI2: J1.E (PHI2), J2.8, J3.E (PHI2)
R/!W: J1.5 (R/!W), J2.5, J3.5 (R/!W)

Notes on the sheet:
Reichelt SIL 9-8 10K
Cart64out
Break out for Expansion Slot
Sven Petersen
122-1-01-01
http://github.com/svenpetersen1965
6x6mm tact switch

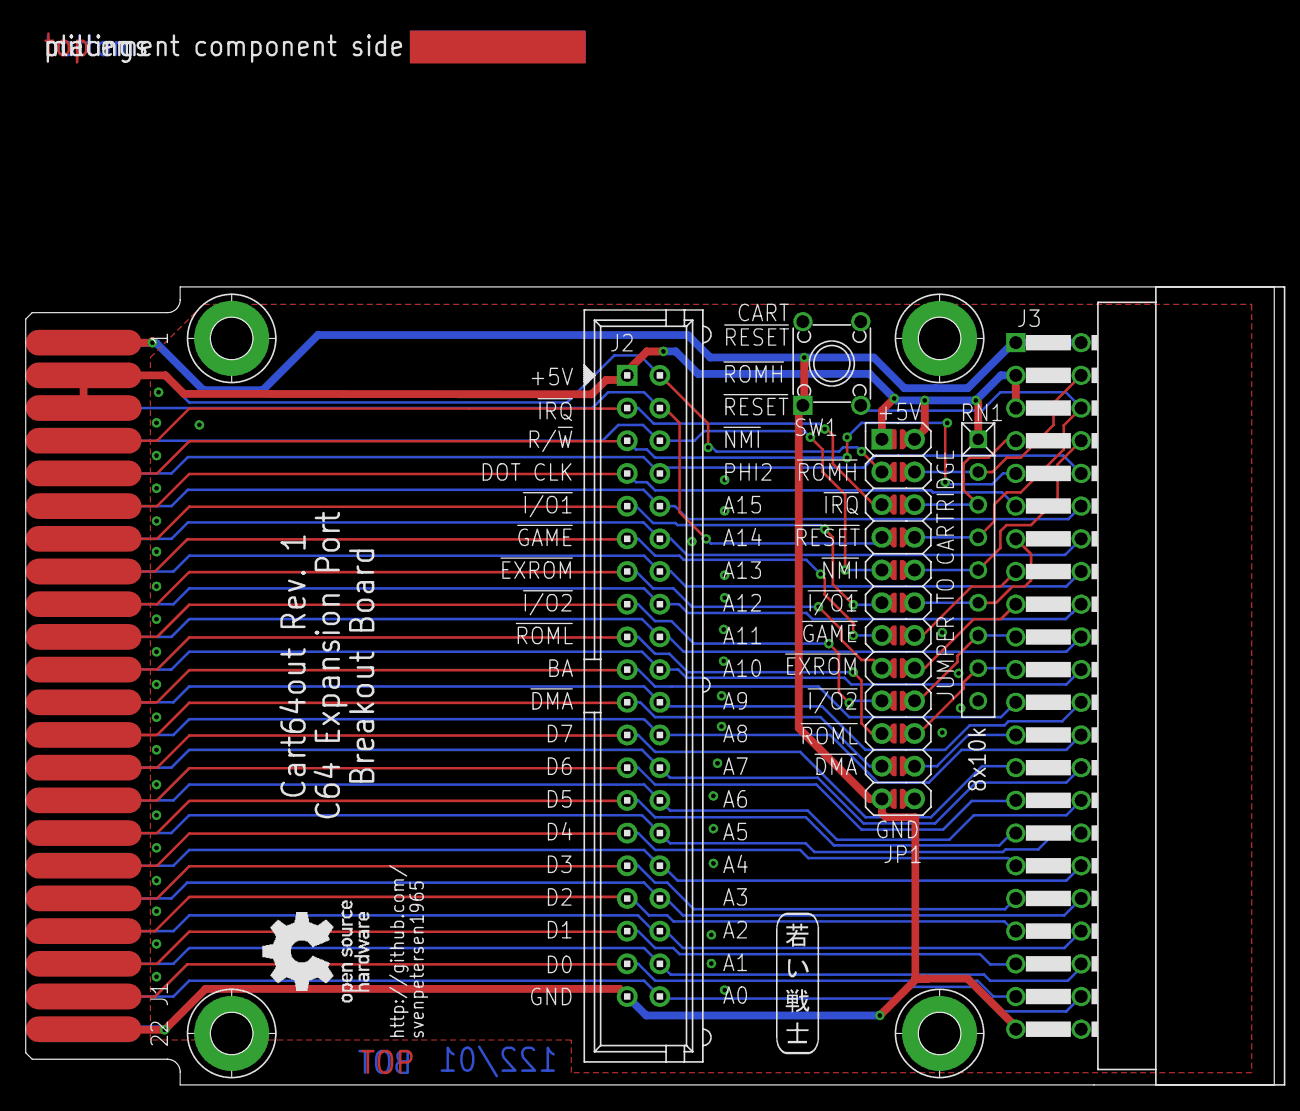
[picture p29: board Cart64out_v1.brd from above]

Board: 2 copper layers, 97.0 x 62.0 mm, 14 parts (0 on the bottom side), 50 nets.

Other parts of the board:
U$20: 2LAYER
U$21: PCB-TITLE/
U$23: SVEN_TAG

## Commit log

2020-06-09 Calculation of BOM
    Component prices added
    [Cart64Out_BOM_v0_0_calc.xlsx]
2020-08-10 Silk Screen Update
    [Cart64out.brd, Cart64out.sch]
2021-11-16 Doc Update
    New dimensions added
    [Cart64out.brd]
2021-11-16 dxf file new
    [Cart64out.dxf]
2022-02-08 Generated a version with four mounting holes
    [Cart64out_0a.brd, Cart64out_0a.sch]
2022-10-29 Rev. 1 released
    [Cart64Out_BOM_v1_0.xlsx, Cart64out_v1.brd, Cart64out_v1.dxf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]
